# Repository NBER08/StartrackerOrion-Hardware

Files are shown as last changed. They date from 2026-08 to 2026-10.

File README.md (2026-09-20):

<p align="center" width="100%">
  
</p>

<h1 align="center">Orion Main</h1>

<p align="center" width="100%">
  <a href="https://github.com/NBER08/StartrackerOrion-Hardware/actions/workflows/ci.yaml">
    
  </a>
</p>

<p align="center" width="100%">
    
</p>

***

<p align="center">
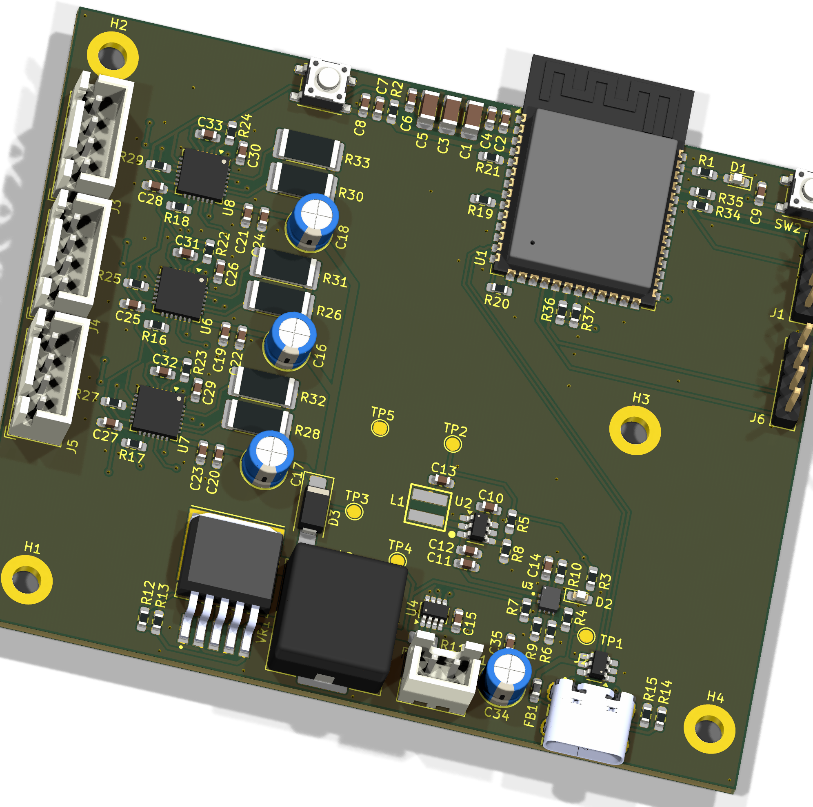
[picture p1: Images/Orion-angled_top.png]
3D Top Angled
  
&nbsp; &nbsp; &nbsp; &nbsp;
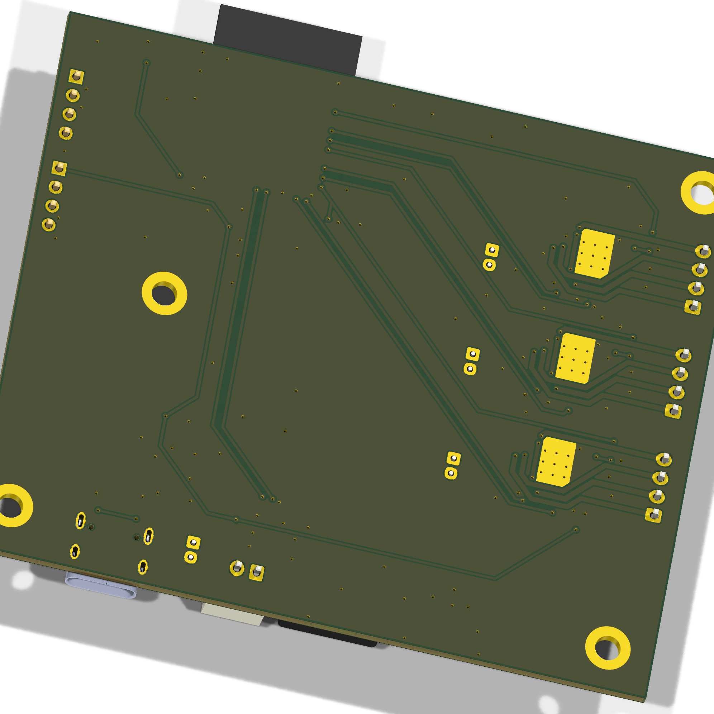
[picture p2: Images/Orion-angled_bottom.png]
3D Bottom Angled
  
</p>

***

## SPECIFICATIONS

| Parameter | Value | 
| --- | --- |
| Dimensions | 86.06 × 71.93 mm |

***

## DIRECTORY STRUCTURE

    .
    ├─ Computations       # Misc calculations
    ├─ HTML               # HTML files for generated webpage
    ├─ Images             # Pictures and renders
    │
    ├─ kibot_resources    # External resources for KiBot
    │  ├─ colors          # Color theme for KiCad
    │  ├─ fonts           # Fonts used in the project
    │  ├─ scripts         # External scripts used with KiBot
    │  └─ templates       # Templates for KiBot generated reports
    │
    ├─ kibot_yaml         # KiBot YAML config files
    ├─ KiRI               # KiRI (PCB diff viewer) files
    │
    ├─ lib                # KiCad footprint and symbol libraries
    │  ├─ 3d_models       # Component 3D models
    │  ├─ lib_fp          # Footprint libraries
    │  └─ lib_sym         # Symbol libraries
    │
    ├─ Logos              # Logos
    │
    ├─ Manufacturing      # Assembly and fabrication documents
    │  ├─ Assembly        # Assembly documents (BoM, pos, notes)
    │  │
    │  └─ Fabrication     # Fabrication documents (ZIP, notes)
    │     ├─ Drill Tables # CSV drill tables
    │     └─ Gerbers      # Gerbers
    │
    ├─ Report             # Reports for ERC/DRC
    ├─ Schematic          # PDF of schematic
    ├─ Templates          # Title block templates
    ├─ Testing
    │  └─ Testpoints      # Testpoints tables      
    │
    └─ Variants           # Outputs for assembly variants

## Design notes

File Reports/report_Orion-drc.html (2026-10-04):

Logo

(https://github.com/INTI-CMNB/KiBot/) | DRC report for Orion
| PCB: Orion Revision: + (Unreleased) Date: 2026-10-04T15:30:59 KiCad Version: 10.0.5 | Errors: 0 (+7 excluded) Warnings: 0 (+4 excluded) Total: 0 (+11 excluded)

✔

Violations

Type | Description | Details
silk_edge_clearance | Silkscreen clipped by board edge | @(64.2638 mm, 33.9054 mm): Rectangle on Edge.Cuts @(128.577 mm, 105.0246 mm): Segment of J2 on F.Silkscreen
silk_edge_clearance | Silkscreen clipped by board edge | @(64.2638 mm, 33.9054 mm): Rectangle on Edge.Cuts @(137.517 mm, 106.3046 mm): Segment of J2 on F.Silkscreen
silk_edge_clearance | Silkscreen clipped by board edge | @(64.2638 mm, 33.9054 mm): Rectangle on Edge.Cuts @(113.6238 mm, 27.7132 mm): Segment of U1 on F.Silkscreen
silk_edge_clearance | Silkscreen clipped by board edge | @(64.2638 mm, 33.9054 mm): Rectangle on Edge.Cuts @(132.0238 mm, 27.7132 mm): Segment of U1 on F.Silkscreen
clearance | Clearance violation (rule 'pad to pad clearance (without hole, different nets)' clearance 0.2000 mm; actual 0.1500 mm) | @(114.0667 mm, 94.7782 mm): Pad 2 [Net-(BT1-+)] of U4 on L1 (Sig, PWR) @(114.7167 mm, 94.7782 mm): Pad 3 [GND] of U4 on L1 (Sig, PWR)
clearance | Clearance violation (rule 'pad to pad clearance (without hole, different nets)' clearance 0.2000 mm; actual 0.1500 mm) | @(114.0667 mm, 94.7782 mm): Pad 2 [Net-(BT1-+)] of U4 on L1 (Sig, PWR) @(113.4167 mm, 94.7782 mm): Pad 1 [+BATT] of U4 on L1 (Sig, PWR)
clearance | Clearance violation (rule 'pad to pad clearance (without hole, different nets)' clearance 0.2000 mm; actual 0.1500 mm) | @(114.7167 mm, 94.7782 mm): Pad 3 [GND] of U4 on L1 (Sig, PWR) @(115.3667 mm, 94.7782 mm): Pad 4 [+3.3V] of U4 on L1 (Sig, PWR)
clearance | Clearance violation (rule 'pad to pad clearance (without hole, different nets)' clearance 0.2000 mm; actual 0.1500 mm) | @(115.3667 mm, 92.5032 mm): Pad 5 [/Project Architecture/MCU/INA_SCL] of U4 on L1 (Sig, PWR) @(114.7167 mm, 92.5032 mm): Pad 6 [/Project Architecture/MCU/INA_SDA] of U4 on L1 (Sig, PWR)
clearance | Clearance violation (rule 'pad to pad clearance (without hole, different nets)' clearance 0.2000 mm; actual 0.1500 mm) | @(114.7167 mm, 92.5032 mm): Pad 6 [/Project Architecture/MCU/INA_SDA] of U4 on L1 (Sig, PWR) @(114.0667 mm, 92.5032 mm): Pad 7 [GND] of U4 on L1 (Sig, PWR)
hole_clearance | Hole clearance violation (rule 'NPTH with copper around' clearance 0.2000 mm; actual 0.1751 mm) | @(129.847 mm, 98.9496 mm): Pad A1_B12 [GND] of J2 on L1 (Sig, PWR) @(130.157 mm, 100.0246 mm): NPTH pad of J2
hole_clearance | Hole clearance violation (rule 'NPTH with copper around' clearance 0.2000 mm; actual 0.1751 mm) | @(136.247 mm, 98.9496 mm): Pad B1_A12 [GND] of J2 on L1 (Sig, PWR) @(135.937 mm, 100.0246 mm): NPTH pad of J2

Generated by KiBot (https://github.com/INTI-CMNB/KiBot/) v1.9.2

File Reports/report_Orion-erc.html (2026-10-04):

Logo

(https://github.com/INTI-CMNB/KiBot/) | ERC report for Orion
| Schematic: Orion Revision: + (Unreleased) Date: 2026-10-04T15:30:54 KiCad Version: 10.0.5 | Errors: 0 (+1 excluded) Warnings: 1 (+15 excluded) Total: 1 (+16 excluded)

Sheet / (Orion.kicad_sch)

Type | Description | Details
footprint_link_issues | The current configuration does not include the footprint library 'TPS2121RUXR' | @(0.8255 mm, 0.8636 mm): Symbol U3 [TPS2121RUXR]
lib_symbol_mismatch | Symbol doesn't match copy in library | @(0.6985 mm, 0.5588 mm): Symbol C30 [C_Small]
lib_symbol_mismatch | Symbol doesn't match copy in library | @(0.8382 mm, 0.8001 mm): Symbol C33 [C_Small]
lib_symbol_mismatch | Symbol doesn't match copy in library | @(1.5367 mm, 0.5334 mm): Symbol C26 [C_Small]
lib_symbol_mismatch | Symbol doesn't match copy in library | @(1.6764 mm, 0.7747 mm): Symbol C31 [C_Small]
lib_symbol_mismatch | Symbol doesn't match copy in library | @(2.3749 mm, 0.5461 mm): Symbol C29 [C_Small]
lib_symbol_mismatch | Symbol doesn't match copy in library | @(2.5146 mm, 0.7874 mm): Symbol C32 [C_Small]
lib_symbol_mismatch | Symbol doesn't match copy in library | @(0.6223 mm, 1.016 mm): Symbol C14 [C_Small]
lib_symbol_mismatch | Symbol doesn't match copy in library | @(2.0574 mm, 0.7112 mm): Symbol C10 [C_Small]

Sheet /Project Architecture/Power/ (power.kicad_sch)

Type | Description | Details
power_pin_not_driven | Input Power pin not driven by any Output Power pins | @(1.7907 mm, 0.7112 mm): Symbol U2 Pin 3 [VIN, Power input, Line]

Sheet /Project Architecture/Connectors/ (conn.kicad_sch)

Type | Description | Details
multiple_net_names | More than one name given to this bus or net | @(0.7747 mm, 0.5969 mm): Symbol #PWR030 Pin 1 [Power input, Line] @(0.6731 mm, 0.7493 mm): Symbol J2 Hidden pin SH2 [SHELL_GND, Power input, Line]

Sheet /Project Architecture/Drivers/ (drivers.kicad_sch)

Type | Description | Details
multiple_net_names | More than one name given to this bus or net | @(0.3429 mm, 0.8001 mm): Global Label 'RX1' @(0.5461 mm, 1.2827 mm): Global Label 'TX1'
multiple_net_names | More than one name given to this bus or net | @(0.5461 mm, 1.3081 mm): Global Label 'RX1' @(0.5461 mm, 1.2827 mm): Global Label 'TX1'
multiple_net_names | More than one name given to this bus or net | @(1.3843 mm, 1.2827 mm): Global Label 'RX2' @(1.1303 mm, 0.7239 mm): Global Label 'TX2'
multiple_net_names | More than one name given to this bus or net | @(1.3843 mm, 1.2827 mm): Global Label 'RX2' @(1.3843 mm, 1.2573 mm): Global Label 'TX2'
multiple_net_names | More than one name given to this bus or net | @(1.9812 mm, 0.7874 mm): Global Label 'RX3' @(1.9812 mm, 0.7366 mm): Global Label 'TX3'
multiple_net_names | More than one name given to this bus or net | @(2.2352 mm, 1.2954 mm): Global Label 'RX3' @(2.2352 mm, 1.27 mm): Global Label 'TX3'

Generated by KiBot (https://github.com/INTI-CMNB/KiBot/) v1.9.2

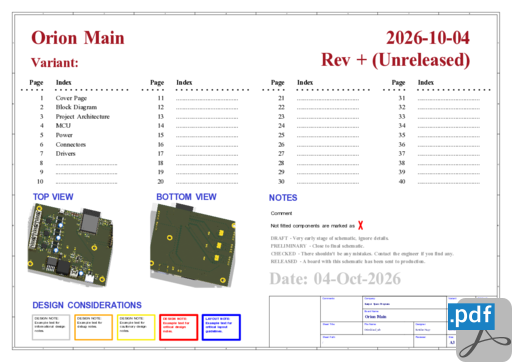
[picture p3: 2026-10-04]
HTML/images/cat_pdf_schematic_Orion-schematic.png

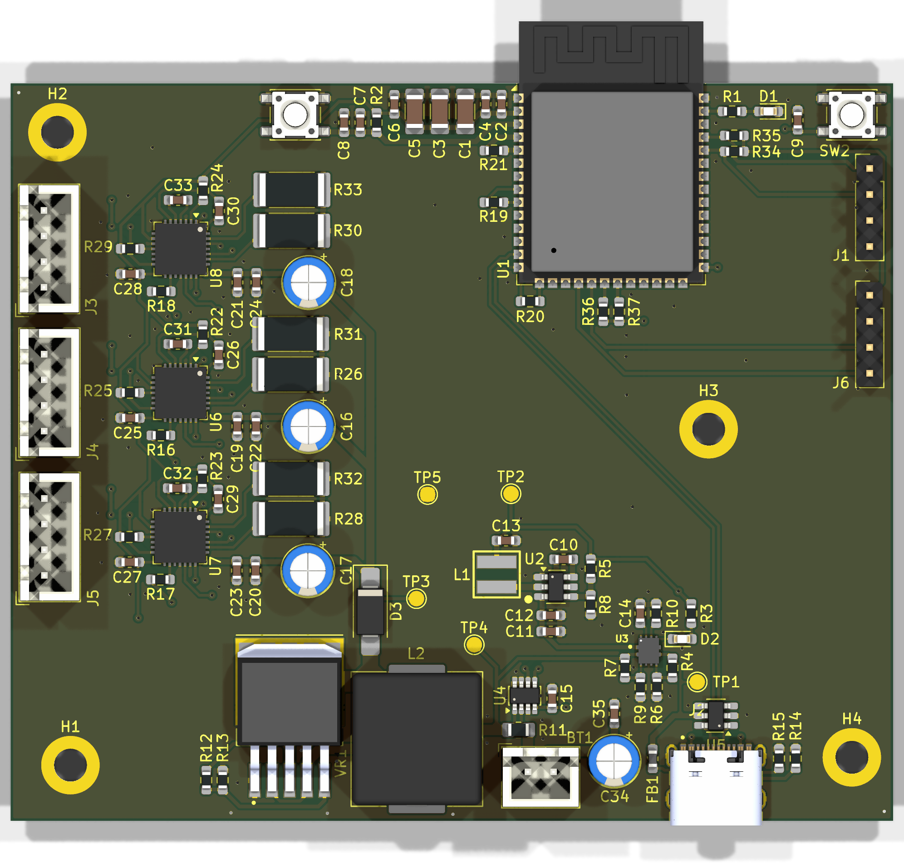
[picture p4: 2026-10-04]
Images/Orion-top.png

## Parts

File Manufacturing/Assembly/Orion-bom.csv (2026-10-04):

Row | Quantity Per PCB | References | Value | Datasheet | Footprint | Description | Manufacturer | Manufacturer Part Number | Supplier Part Number
1 | 1 | BT1 | Battery |  | JST_XH_B2B-XH-A_1x02_P2.50mm_Vertical | Multiple-cell battery
2 | 1 | C2 | 22p |  | C_0603_1608Metric_Pad1.08x0.95mm_HandSolder | Unpolarized capacitor
3 | 3 | C31 C32 C33 | 22n |  | C_0603_1608Metric_Pad1.08x0.95mm_HandSolder | 50V
4 | 19 | C6 C8 C9 C10 C12 C15 C19 C20 C21 C22 C23 C24 C25 C26 C27 C28 C29 C30 C35 | 100n |  | C_0603_1608Metric_Pad1.08x0.95mm_HandSolder | Unpolarized capacitor Unpolarized capacitor, small symbol 16V
5 | 2 | C11 C14 | 1u |  | C_0603_1608Metric_Pad1.08x0.95mm_HandSolder | Unpolarized capacitor Unpolarized capacitor, small symbol
6 | 1 | C7 | 10u |  | C_0603_1608Metric_Pad1.08x0.95mm_HandSolder | Unpolarized capacitor
7 | 1 | C4 | 22u |  | C_0603_1608Metric_Pad1.08x0.95mm_HandSolder | Unpolarized capacitor
8 | 2 | C13 L2 | 47u |  | C_0603_1608Metric_Pad1.08x0.95mm_HandSolder | Unpolarized capacitor Inductor
9 | 7 | C1 C3 C5 C16 C17 C18 C34 | 100u |  | C_1206_3216Metric_Pad1.33x1.80mm_HandSolder | Unpolarized capacitor low ESR
10 | 2 | D1 D2 | RED |  | LED_0603_1608Metric_Pad1.05x0.95mm_HandSolder | Light emitting diode
11 | 1 | D3 | SS34 | https://www.vishay.com/docs/88751/ss32.pdf | D_SMA_Handsoldering | 40V 3A Schottky Diode, SMA
12 | 1 | FB1 | LI0603G121R-10 |  | L_0603_1608Metric_Pad1.05x0.95mm_HandSolder | Ferrite bead
13 | 5 | J1 J3 J4 J5 J6 | Conn_01x04_Pin |  | PinHeader_1x04_P2.54mm_Vertical | Generic connector, single row, 01x04, script generated
14 | 1 | J2 | USB4105GFA |  | GCT_USB4105GFA | USB-C (USB TYPE-C) USB 2.0 Receptacle Connector 24 (16+8 Dummy) Position Surface Mount, Right Angle; Through Hole | Global Connector Technology
15 | 1 | L1 | 5u6 |  | WE-XHMI_4040 | Inductor
16 | 1 | R11 | 10m |  | R_0805_2012Metric_Pad1.20x1.40mm_HandSolder | Resistor
17 | 6 | R26 R28 R30 R31 R32 R33 | 220m |  | R_2512_6332Metric_Pad1.40x3.35mm_HandSolder | Resistor, small symbol
18 | 2 | R1 R3 | 120 |  | R_0603_1608Metric_Pad0.98x0.95mm_HandSolder | Resistor
19 | 1 | R13 | 330 |  | R_0603_1608Metric_Pad0.98x0.95mm_HandSolder | Resistor
20 | 6 | R16 R17 R18 R19 R20 R21 | 1k |  | R_0603_1608Metric_Pad0.98x0.95mm_HandSolder | Resistor, small symbol
21 | 1 | R12 | 2k8 |  | R_0603_1608Metric_Pad0.98x0.95mm_HandSolder | Resistor
22 | 2 | R14 R15 | 5k1 |  | R_0603_1608Metric_Pad0.98x0.95mm_HandSolder | Resistor
23 | 7 | R2 R22 R23 R24 R25 R27 R29 | 10k |  | R_0603_1608Metric_Pad0.98x0.95mm_HandSolder | Resistor Resistor, small symbol
24 | 1 | R10 | 21k5 |  | R_0603_1608Metric_Pad0.98x0.95mm_HandSolder | Resistor, small symbol
25 | 1 | R8 | 22k1 |  | R_0603_1608Metric_Pad0.98x0.95mm_HandSolder | Resistor, small symbol
26 | 2 | R6 R9 | 33k |  | R_0603_1608Metric_Pad0.98x0.95mm_HandSolder | Resistor, small symbol
27 | 5 | R4 R34 R35 R36 R37 | 47k |  | R_0603_1608Metric_Pad0.98x0.95mm_HandSolder | Resistor, small symbol
28 | 1 | R7 | 82k |  | R_0603_1608Metric_Pad0.98x0.95mm_HandSolder | Resistor, small symbol
29 | 1 | R5 | 100k |  | R_0603_1608Metric_Pad0.98x0.95mm_HandSolder | Resistor, small symbol
30 | 1 | SW2 | BOOT |  | SW_SPST_PTS647_Sx38 | Push button switch, generic, two pins
31 | 1 | SW1 | RST |  | SW_SPST_PTS647_Sx38 | Push button switch, generic, two pins
32 | 1 | U1 | ESP32-S3-WROOM-1 | https://www.espressif.com/sites/default/files/documentation/esp32-s3-wroom-1_wroom-1u_datasheet_en.pdf | ESP32-S3-WROOM-1_novias | RF Module, ESP32-S3 SoC, Wi-Fi 802.11b/g/n, Bluetooth, BLE, 32-bit, 3.3V, onboard antenna, SMD
33 | 1 | U4 | INA219BxDCN | http://www.ti.com/lit/ds/symlink/ina219.pdf | SOT-23-8 | Zero-Drift, HighAccuracy, Bidirectional Current/Power Monitor (0-26V) With I2C Interface, SOT-23-8
34 | 1 | U2 | LMR51420 | https://www.ti.com/lit/ds/symlink/lmr51430.pdf | SOT-23-6_Handsoldering | 4.5-V to 36-V, 3-A synchronous buck converter with 40-µA IQ, SOT-23-6
35 | 1 | U5 | SRV05-4 | http://www.onsemi.com/pub/Collateral/SRV05-4-D.PDF | SOT-23-6_Handsoldering | ESD Protection Diodes with Low Clamping Voltage, SOT-23-6
36 | 3 | U6 U7 U8 | TMC2209-LA | https://www.analog.com/media/en/technical-documentation/data-sheets/TMC2209_datasheet_rev1.09.pdf | VQFN-28-1EP_5x5mm_P0.5mm_EP3.7x3.7mm | 2-phase stepper motor driver, 256 µSteps, 2.8A peak, 2.0A RMS, VS = 4.75..29V, STEP/DIR and UART interface, VQFN-28
37 | 1 | U3 | TPS2121RUXR |  | IC_TPS2121RUXR | 2.7-V to 22-V, 56-mΩ, 4.5-A, power mux with seamless switchover | TEXAS INSTRUMENTS
38 | 1 | VR1 | XL6009 |  | DPAK170P1435X465-6N | The XL6009 regulator is a wide input range, current mode, DC/DC converter which is capable of generating either positive or negative output voltages. | XLSEMI

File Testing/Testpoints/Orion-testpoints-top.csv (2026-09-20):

Ref. | Net | X [mm] | Y [mm]
TP1 | VBUS | 67.22 | 13.70
TP2 | +3.3V | 49.06 | 32.06
TP3 | VM | 39.84 | 21.83
TP4 | +BATT | 45.48 | 17.33
TP5 | GND | 40.93 | 31.99

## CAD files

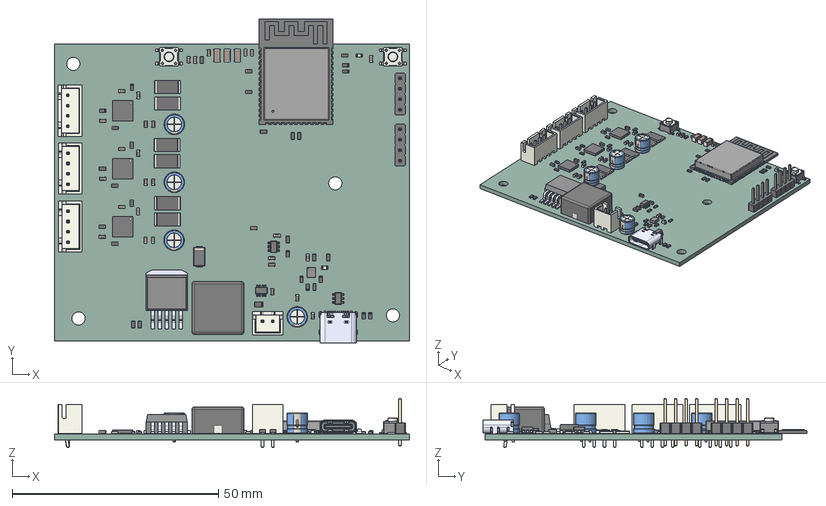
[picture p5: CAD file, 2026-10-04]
3D/Orion.step
86.1 x 78.4 x 11.9 mm
C_0603_1608Metric x 28
R_2512_6332Metric x 6
SOT-23-6 x 2
LED_0603_1608Metric x 2
SW_SPST_PTS647Sx38 x 2
JST_B4B_XH_A x 3
R_0603_1608Metric x 30
USB4105GFA_USB4105GFA
CP_Radial_D50mm_P200mm x 4
PinHeader_1x04_P254mm_Vertical x 2
SOT-23-8
JST_B2B_XH_A
XL6009
QFN-28-1EP_5x5mm_Pitch0.5mm x 3
L_Changjiang_FXL1365
C_1206_3216Metric x 3
L_0603_1608Metric
TPS2121RUXR
R_0805_2012Metric
D_SMA
ESP32-S3-WROOM-1
kibot_7lxlktsg_PCB

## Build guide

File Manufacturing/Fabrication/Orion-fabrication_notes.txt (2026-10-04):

FABRICATION NOTES (UNLESS OTHERWISE SPECIFIED)

1)	FABRICATE PER IPC-6012A CLASS 2.

2)	OUTLINE DEFINED IN SEPARATE GERBER FILE WITH
	"Edge_Cuts.GBR" SUFFIX.

	DIMENSIONS OF CIRCUMSIZED RECTANGLE SHOWN ON THIS
	DRAWING FOR REFERENCE ONLY.

3)	SEE SEPARATE DRILL FILES WITH ".DRL" SUFFIX 
	FOR HOLE LOCATIONS.

	SELECTED HOLE LOCATIONS SHOWN ON THIS DRAWING 
	FOR REFERENCE ONLY.

4)	SURFACE FINISH: ENIG

5)	SOLDERMASK ON BOTH SIDES OF THE BOARD SHALL 
	BE LPI, COLOR GREEN.

6)	SILK SCREEN LEGEND TO BE APPLIED PER LAYER 
	STACKUP USING YELLOW NON-CONDUCTIVE EPOXY INK.

7)	ALL VIAS ARE TENTED ON BOTH SIDES UNLESS 
	SOLDERMASK OPENED IN GERBER.

8)	VENDOR SHOULD FOLLOW ROHS COMPLIANT PROCESS 
	AND Pb FREE FOR MANUFACTURING

9)	PCB MATERIAL REQUIREMENTS:

	A.	FLAMMABILITY RATING MUST MEET OR EXCEED 
		UL94V-0 REQUIREMENTS.
	B.	Tg 170 C OR EQUIVALENT.
	C.	EQUIVALENT MATERIAL SHALL BE RoHS COMPLIANT, 
		HALOGEN FREE AND APPROVED BY KARPAT SPACE PROGRAM.

10)	DESIGN GEOMETRY MINIMUM FEATURE SIZES:

	BOARD SIZE				86.055 × 71.933 mm
	BOARD THICKNESS		1.660 mm
	TRACE WIDTH			0.200 mm
	TRACE TO TRACE		0.200 mm
	MIN. HOLE (PTH)			0.300 mm
	MIN. HOLE (NPTH)		0.650 mm
	ANNULAR RING			0.200 mm
	COPPER TO HOLE		0.250 mm
	COPPER TO EDGE		0.250 mm
	HOLE TO HOLE			0.100 mm

11)	REFER TO IMPEDANCE TABLE FOR IMPEDANCE CONTROL REQUIREMENTS.

12)	CONFIRM SPACE WIDTHS AND SPACINGS.

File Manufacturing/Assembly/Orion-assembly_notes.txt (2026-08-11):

ASSEMBLY NOTES (UNLESS OTHERWISE SPECIFIED)

1)	DO NOT POPULATE PARTS ARE MARKED WITH A RED CROSS.

2)	DO NOT POPULATE PARTS ARE NOT PRESENT IN THE BOM.

3)	IF CONFLICTING INFORMATION IS FOUND BETWEEN THE ASSEMBLY
	FILE AND BOM, BOM SHOULD BE USED AS THE MAIN SOURCE.

4)	CONFORMAL COATING IS NOT REQUIRED.

5)	DOT IDENTIFIES PIN #1 LOCATION AND DEVICE ORIENTATION
	WHEN VIEWED FROM THE TOP.

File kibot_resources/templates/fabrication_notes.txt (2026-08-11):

FABRICATION NOTES (UNLESS OTHERWISE SPECIFIED)

1)	FABRICATE PER IPC-6012A CLASS 2.

2)	OUTLINE DEFINED IN SEPARATE GERBER FILE WITH
	"Edge_Cuts.GBR" SUFFIX.

	DIMENSIONS OF CIRCUMSIZED RECTANGLE SHOWN ON THIS
	DRAWING FOR REFERENCE ONLY.

3)	SEE SEPARATE DRILL FILES WITH ".DRL" SUFFIX 
	FOR HOLE LOCATIONS.

	SELECTED HOLE LOCATIONS SHOWN ON THIS DRAWING 
	FOR REFERENCE ONLY.

4)	SURFACE FINISH: ${pcb_finish_cap}

5)	SOLDERMASK ON BOTH SIDES OF THE BOARD SHALL 
	BE LPI, COLOR ${solder_mask_color_text_cap}.

6)	SILK SCREEN LEGEND TO BE APPLIED PER LAYER 
	STACKUP USING ${silk_screen_color_text_cap} NON-CONDUCTIVE EPOXY INK.

7)	ALL VIAS ARE TENTED ON BOTH SIDES UNLESS 
	SOLDERMASK OPENED IN GERBER.

8)	VENDOR SHOULD FOLLOW ROHS COMPLIANT PROCESS 
	AND Pb FREE FOR MANUFACTURING

9)	PCB MATERIAL REQUIREMENTS:

	A.	FLAMMABILITY RATING MUST MEET OR EXCEED 
		UL94V-0 REQUIREMENTS.
	B.	Tg 170 C OR EQUIVALENT.
	C.	EQUIVALENT MATERIAL SHALL BE RoHS COMPLIANT, 
		HALOGEN FREE AND APPROVED BY ${COMPANY_cap}.

10)	DESIGN GEOMETRY MINIMUM FEATURE SIZES:

	BOARD SIZE				${bb_w_mm} × ${bb_h_mm} mm
	BOARD THICKNESS		${thickness_mm} mm
	TRACE WIDTH			${track_mm} mm
	TRACE TO TRACE		${clearance_mm} mm
	MIN. HOLE (PTH)			${drill_pth_real_mm} mm
	MIN. HOLE (NPTH)		${drill_npth_real_mm} mm
	ANNULAR RING			${oar_mm} mm
	COPPER TO HOLE		${c2h_mm} mm
	COPPER TO EDGE		${c2e_mm} mm
	HOLE TO HOLE			${h2h_mm} mm
#?stackup and impedance_controlled

#?stackup and impedance_controlled
11)	REFER TO IMPEDANCE TABLE FOR IMPEDANCE CONTROL REQUIREMENTS.
#?stackup and impedance_controlled

#?stackup and impedance_controlled
12)	CONFIRM SPACE WIDTHS AND SPACINGS.

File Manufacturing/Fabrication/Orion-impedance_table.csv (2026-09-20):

Transmission Line | Impedance [ohms] | Tolerance [ohms] | Layer | Trace Width [mm] | Gap [mm] | Ref. Layers
Edge-Coupled Coated Microstrip | 100 | ±10 % | L1 | 0.285 | 0.1 | L2

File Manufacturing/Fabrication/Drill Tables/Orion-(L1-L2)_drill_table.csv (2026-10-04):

Count | Hole Size | Plated | Hole Shape | Drill Layer Pair | Hole Type
187 | 0.30mm (11.81mils) | PTH | Round | L1 (Sig, PWR) - L4 (Sig, PWR) | Via
4 | 0.60mm (23.62mils) | PTH | Slot | L1 (Sig, PWR) - L4 (Sig, PWR) | Pad
8 | 0.80mm (31.50mils) | PTH | Round | L1 (Sig, PWR) - L4 (Sig, PWR) | Pad
12 | 0.95mm (37.40mils) | PTH | Round | L1 (Sig, PWR) - L4 (Sig, PWR) | Pad
10 | 1.00mm (39.37mils) | PTH | Round | L1 (Sig, PWR) - L4 (Sig, PWR) | Pad
4 | 3.20mm (125.98mils) | PTH | Round | L1 (Sig, PWR) - L4 (Sig, PWR) | Pad
Total 225

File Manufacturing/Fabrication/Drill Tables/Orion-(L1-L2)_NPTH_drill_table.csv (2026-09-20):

Count | Hole Size | Plated | Hole Shape | Drill Layer Pair | Hole Type
2 | 0.65mm (25.59mils) | NPTH | Round | L1 (Sig, PWR) - L4 (Sig, PWR) | Mechanical
Total 2

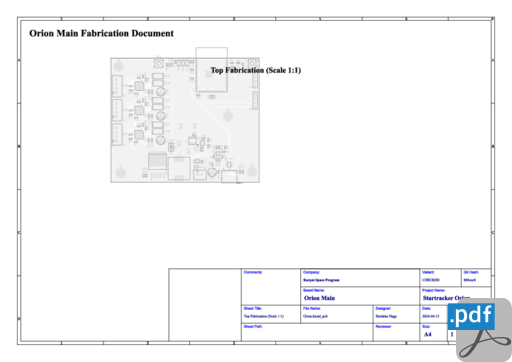
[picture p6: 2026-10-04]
HTML/images/cat_pdf_fabrication_Orion-fabrication.png

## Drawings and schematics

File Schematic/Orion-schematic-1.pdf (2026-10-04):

# Orion Main

# Variant:

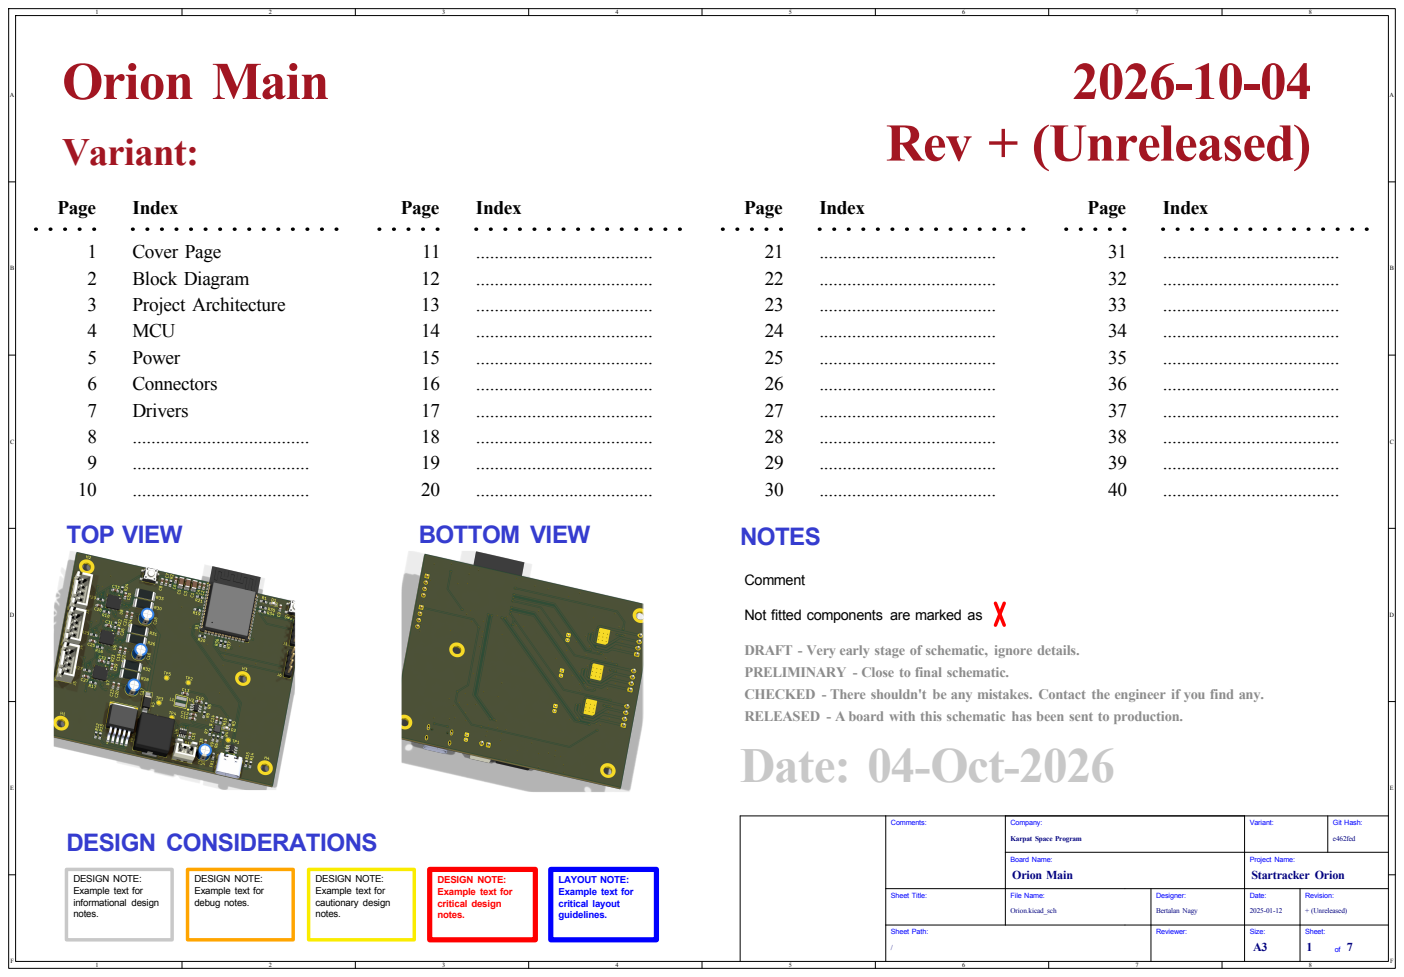
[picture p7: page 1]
Sheet: of 7; Size: A3; Orion.kicad_sch; Bertalan Nagy Board Name: Company:; Variant: Karpat Space Program; Orion Main; Startracker Orion; Sheet Title:; File Name:; /Sheet Path: Comments:; Git Hash: e462fed Block Diagram; kibot_image_png_3d_viewer_angled_top; DESIGN NOTE:; kibot_image_png_3d_viewer_angled_bottom; LAYOUT NOTE:; Page; ...................................... MCU; Project Architecture; Cover Page Block Diagram; Index; TOP VIEW; BOTTOM VIEW; DESIGN CONSIDERATIONS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

...................................... DRAFT - Very early stage of schematic, ignore details.

Not fitted components are marked as

PRELIMINARY - Close to final schematic.
CHECKED - There shouldn't be any mistakes. Contact the engineer if you find any.
RELEASED - A board with this schematic has been sent to production.
Date: 04-Oct-2026

Revision: + (Unreleased) Date: Project Name: 2025-01-12 Reviewer: Designer:

DESIGN NOTE:
Example text for
informational design
notes.

debug notes.

critical design

cautionary design

critical layout
guidelines.

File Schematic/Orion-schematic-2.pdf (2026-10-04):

## Page 4

# [2] Block Diagram

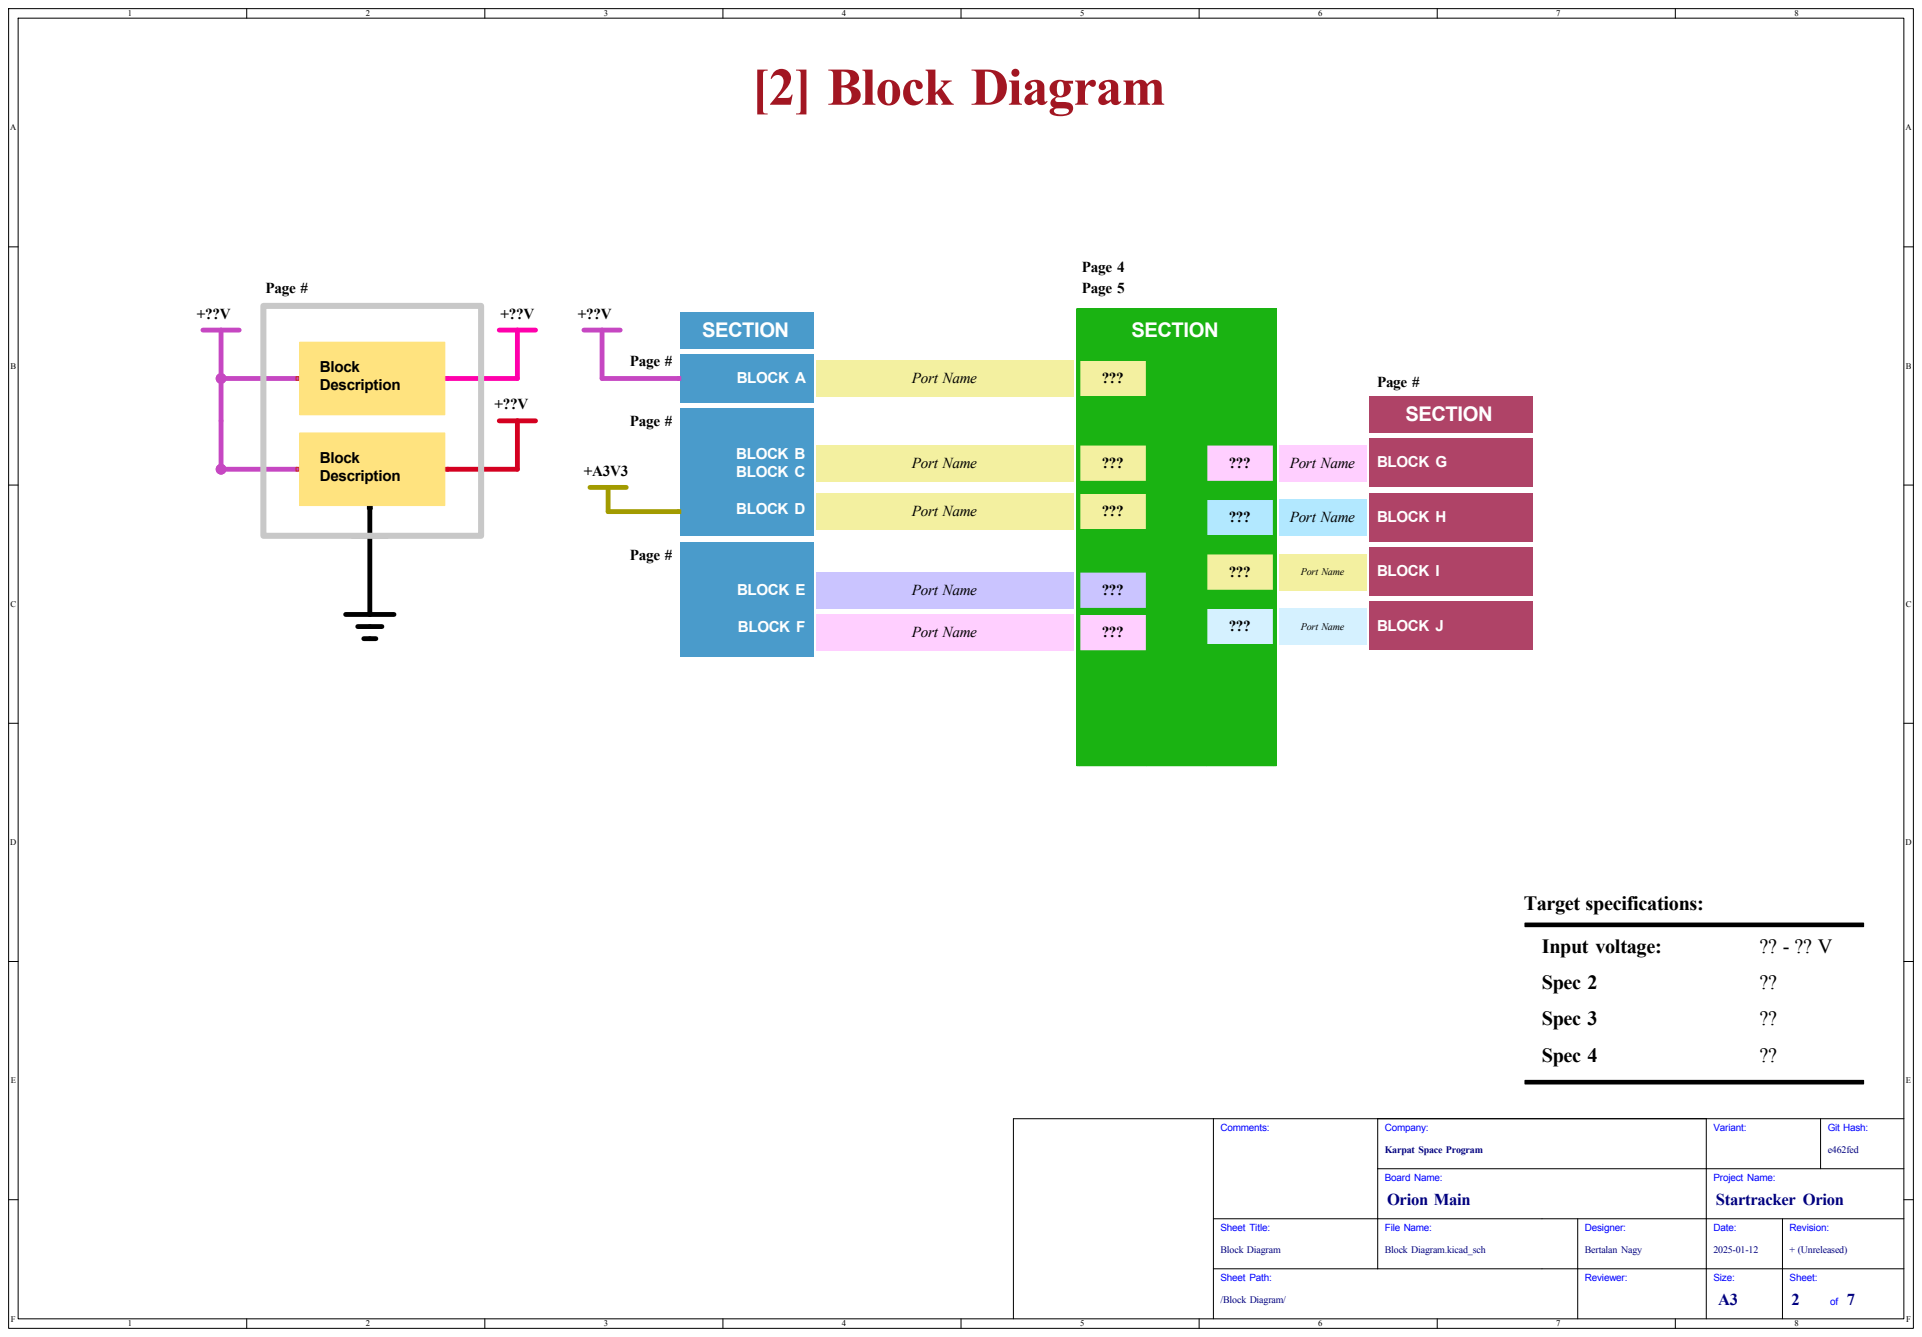
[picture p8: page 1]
Sheet: of 7; Size: A3; Revision: + (Unreleased) Date: Project Name: 2025-01-12 Reviewer: Designer: Block Diagram.kicad_sch; Bertalan Nagy Board Name: Company:; Variant: Karpat Space Program; Orion Main; Startracker Orion; Sheet Title:; File Name:; Comments:; Git Hash: e462fed; Page #; Input voltage:; BLOCK J; BLOCK I; BLOCK H; SECTION; BLOCK G; Spec 3; Spec 4; Spec 2; Port Name; Page 5; Port Name ???; Target specifications:; Block Description; BLOCK B BLOCK C; BLOCK D; BLOCK E; BLOCK F; BLOCK A

Port Name

/Block Diagram/ Sheet Path: Block Diagram

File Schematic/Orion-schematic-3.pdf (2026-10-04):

# INA_SDA MCU [3] Project Architecture

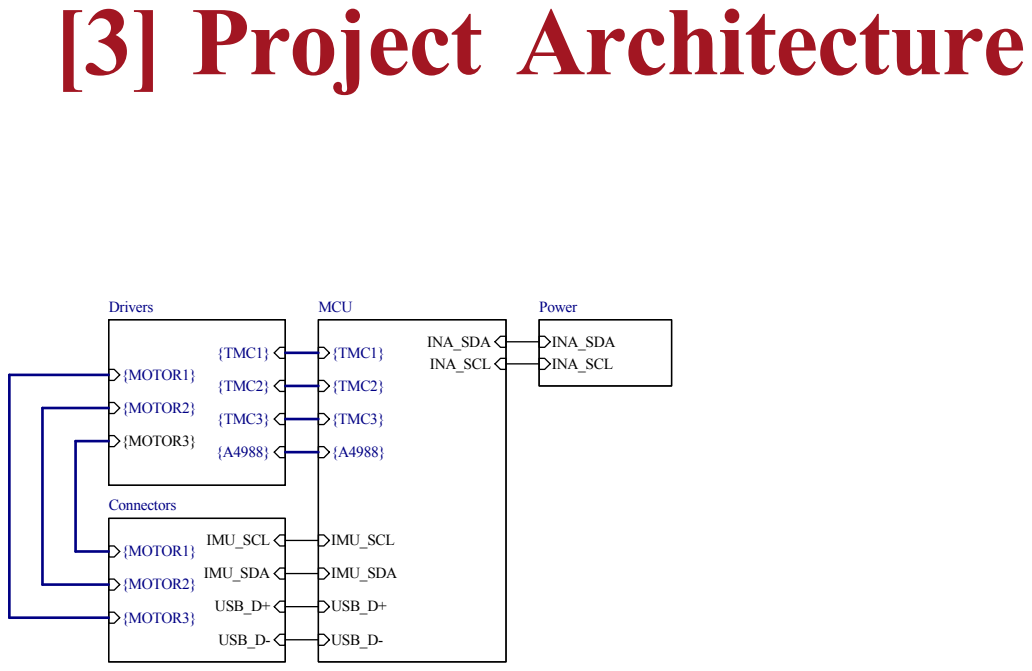
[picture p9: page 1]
Sheet: of 7; Size: A3; Project Architecture.kicad_sch; Bertalan Nagy Board Name: Company:; Variant: Karpat Space Program; Orion Main; Startracker Orion; Sheet Title:; File Name:; /Project Architecture/ Sheet Path: Project Architecture Comments:; Git Hash: e462fed; IMU_SCL; IMU_SDA; USB_D+; USB_D-; {MOTOR1}; {MOTOR2}; {MOTOR3} Connectors; {TMC1}; {MOTOR3}; {TMC2}; {TMC3} Drivers; INA_SCL; INA_SDA; Power; {TMC3}

Revision: + (Unreleased) Date: Project Name: 2025-01-12 Reviewer: Designer:

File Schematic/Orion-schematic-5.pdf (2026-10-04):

# R10 21k5 R3

# [5] Power

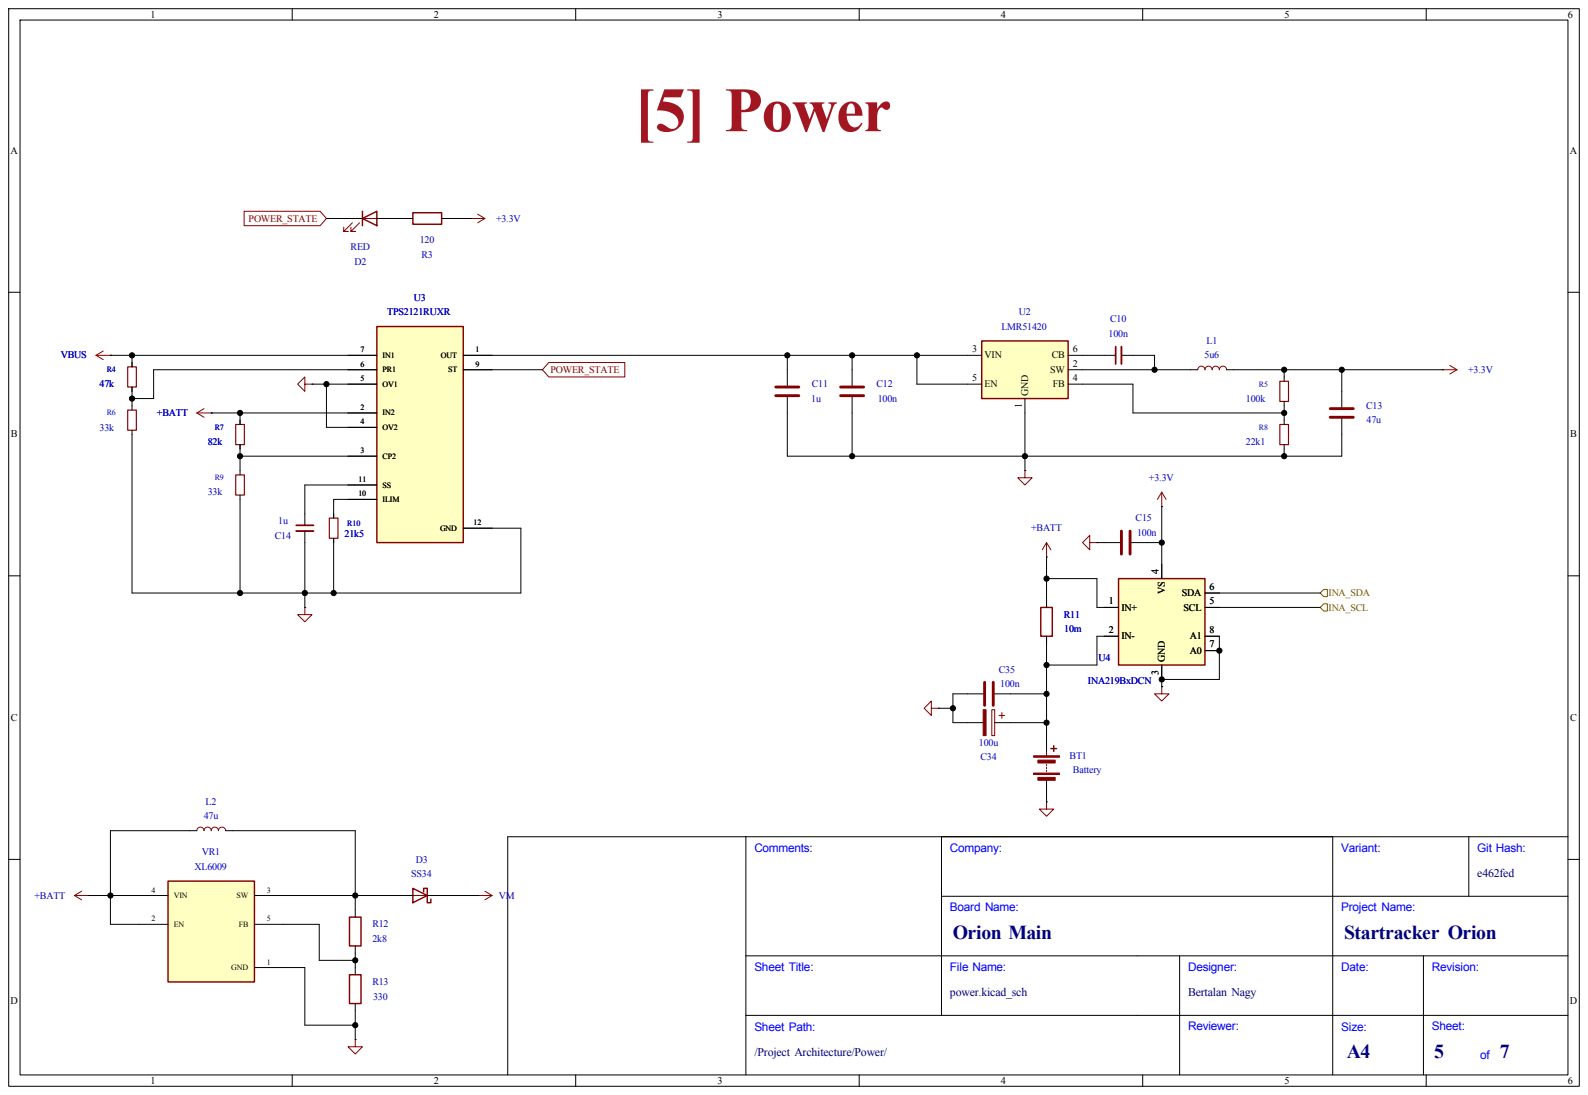
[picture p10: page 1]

1 SW 2 VIN 3 FB 4 EN 5 CB 6 U2 LMR51420 C12

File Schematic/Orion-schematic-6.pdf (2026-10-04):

# [6] Connectors

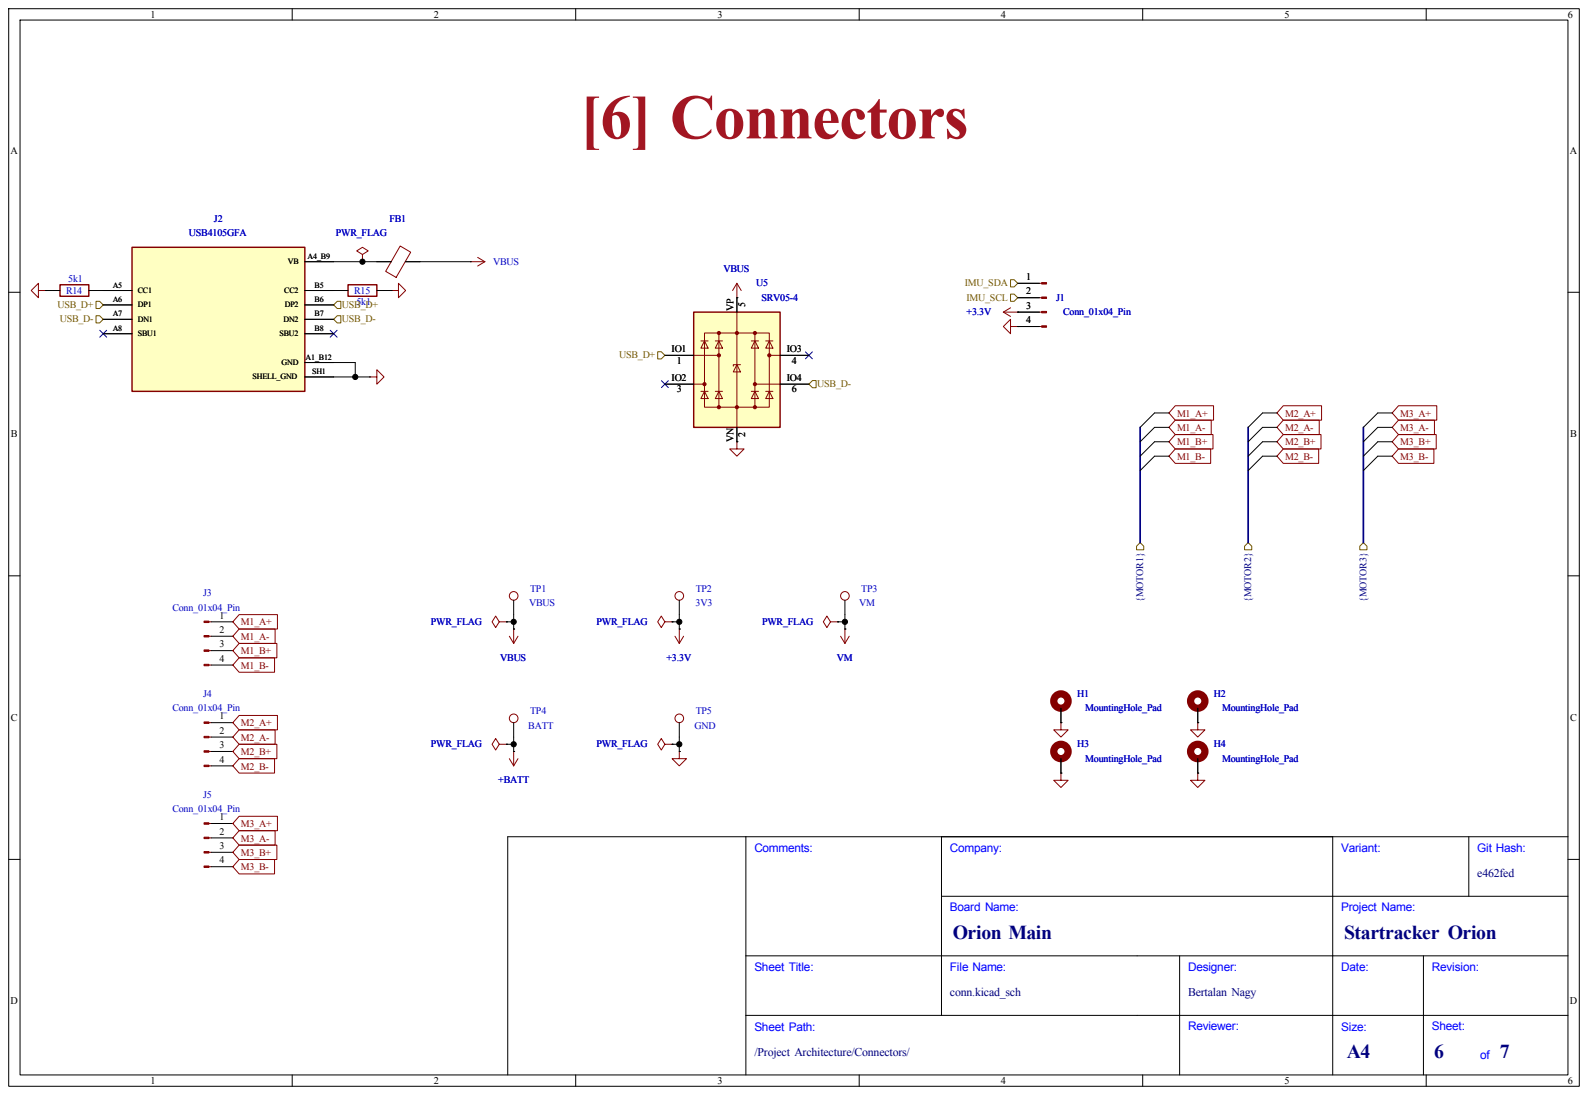
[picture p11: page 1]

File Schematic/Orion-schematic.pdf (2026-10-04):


...................................... DRAFT - Very early stage of schematic, ignore details.

Not fitted components are marked as

PRELIMINARY - Close to final schematic.
CHECKED - There shouldn't be any mistakes. Contact the engineer if you find any.
RELEASED - A board with this schematic has been sent to production.
Date: 04-Oct-2026

Revision: + (Unreleased) Date: Project Name: 2025-01-12 Reviewer: Designer:


Port Name

/Block Diagram/ Sheet Path: Block Diagram


Revision: + (Unreleased) Date: Project Name: 2025-01-12 Reviewer: Designer:

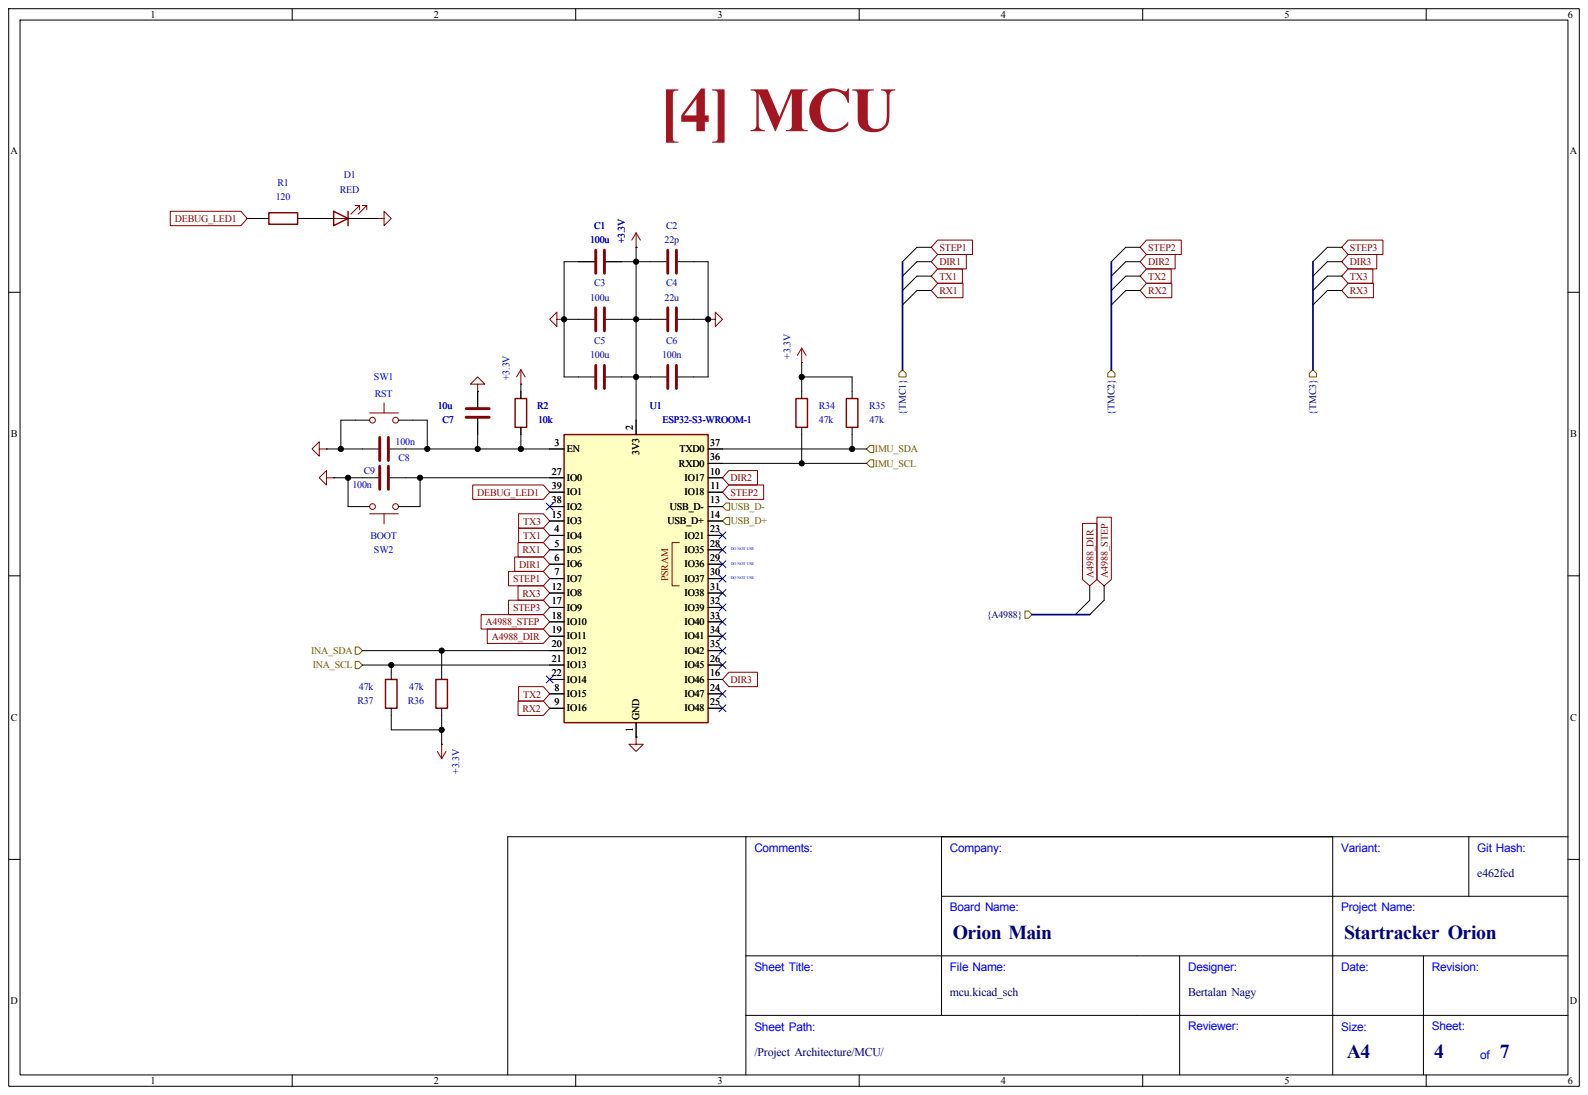
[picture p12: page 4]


1 SW 2 VIN 3 FB 4 EN 5 CB 6 U2 LMR51420 C12


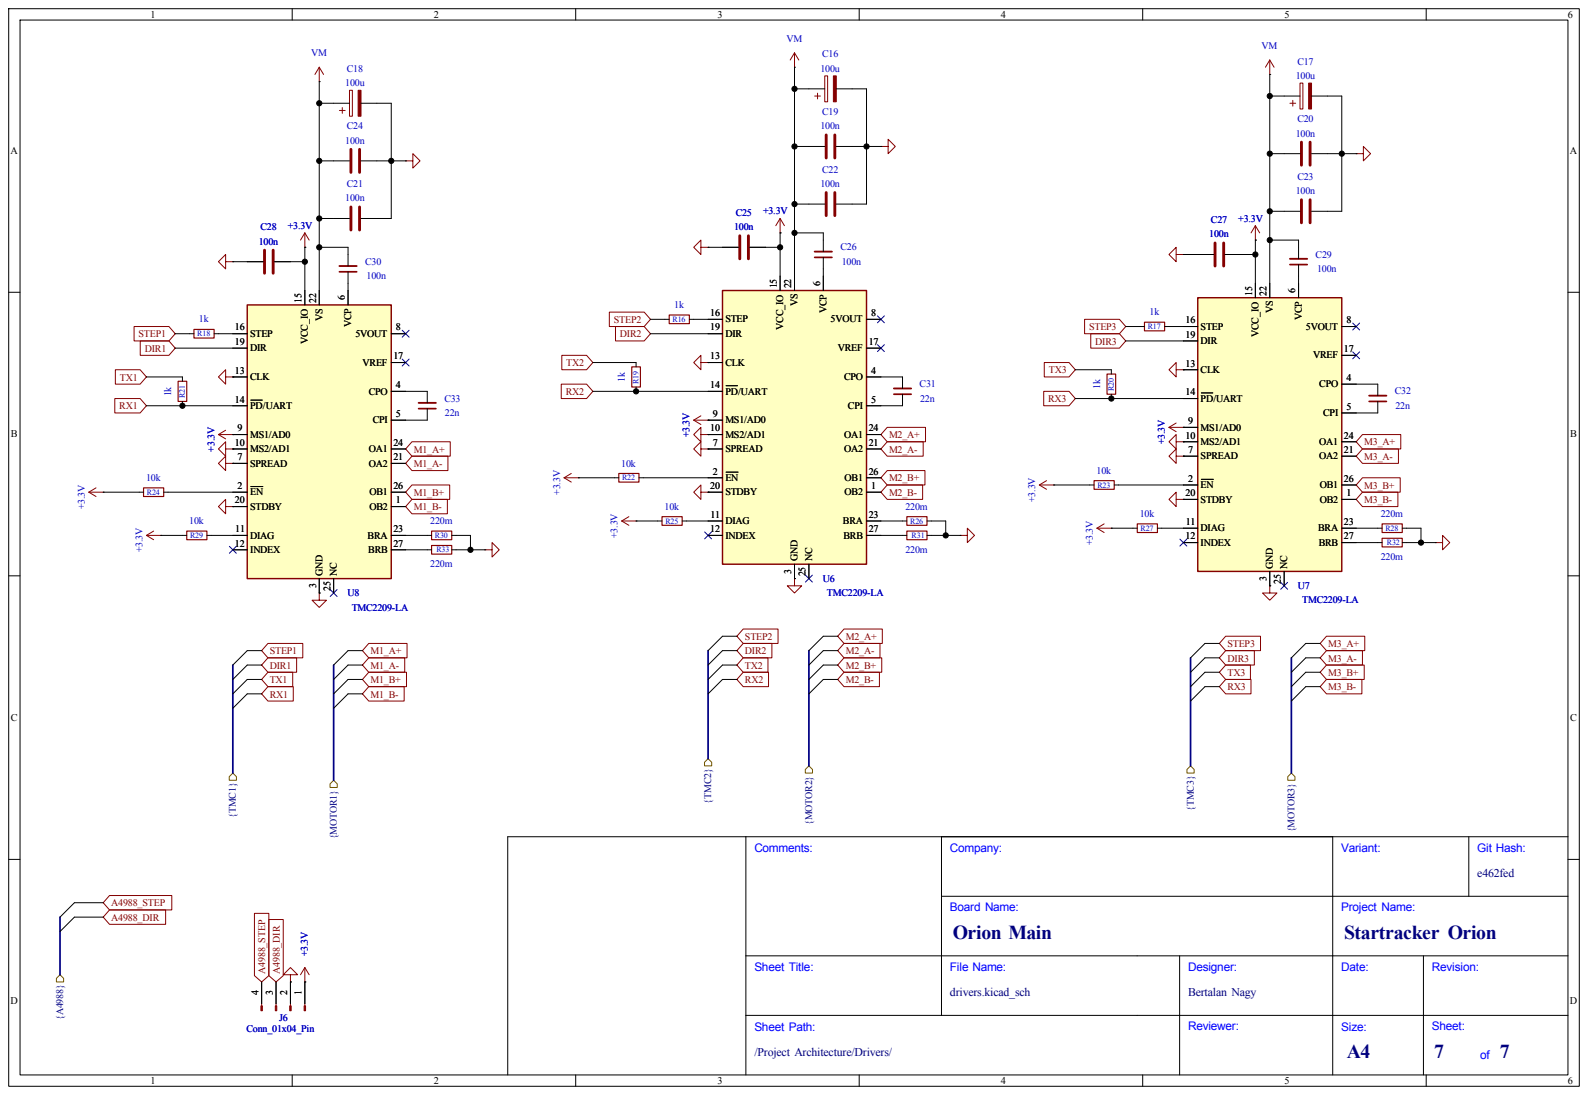
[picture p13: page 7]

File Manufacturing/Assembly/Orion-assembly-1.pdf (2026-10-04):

# Orion Main Assembly Document

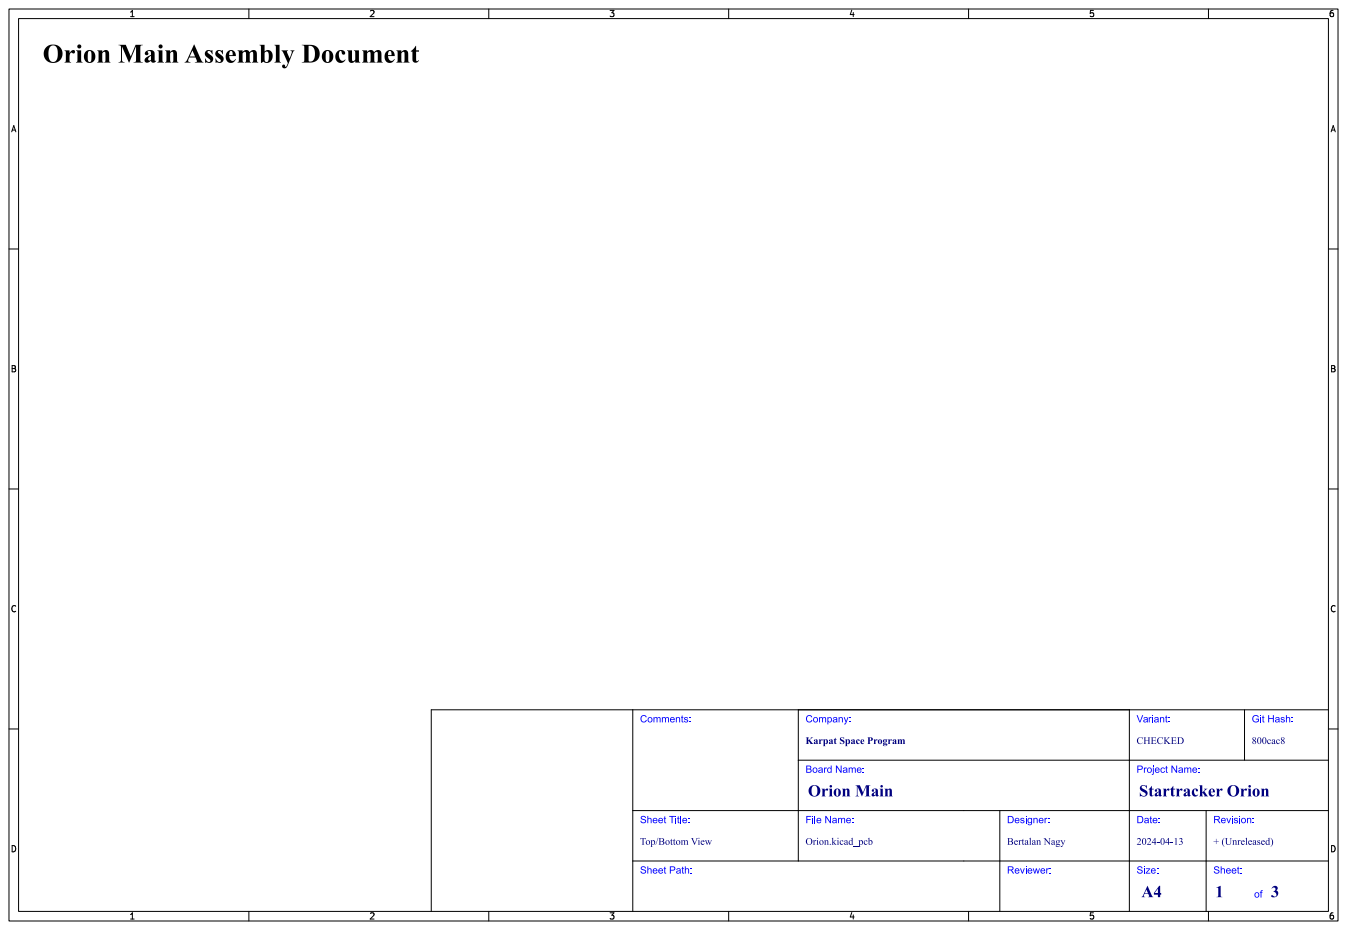
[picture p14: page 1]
Git; Hash:; 800cac8; Comments:; Sheet Path:; Sheet Title:; File Name:; Orion Main; Startracker Orion; Company:; CHECKED; Variant:; Board Name:; Orion.kicad_pcb; Bertalan Nagy; Designer:; Reviewer:; Project Name:; Date:; + (Unreleased); Revision:; Size:; Sheet: 1

Karpat Space Program

Top/Bottom View

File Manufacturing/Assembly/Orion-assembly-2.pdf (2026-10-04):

# Top Assembly (Scale 1:1)

# Orion Main Assembly Document

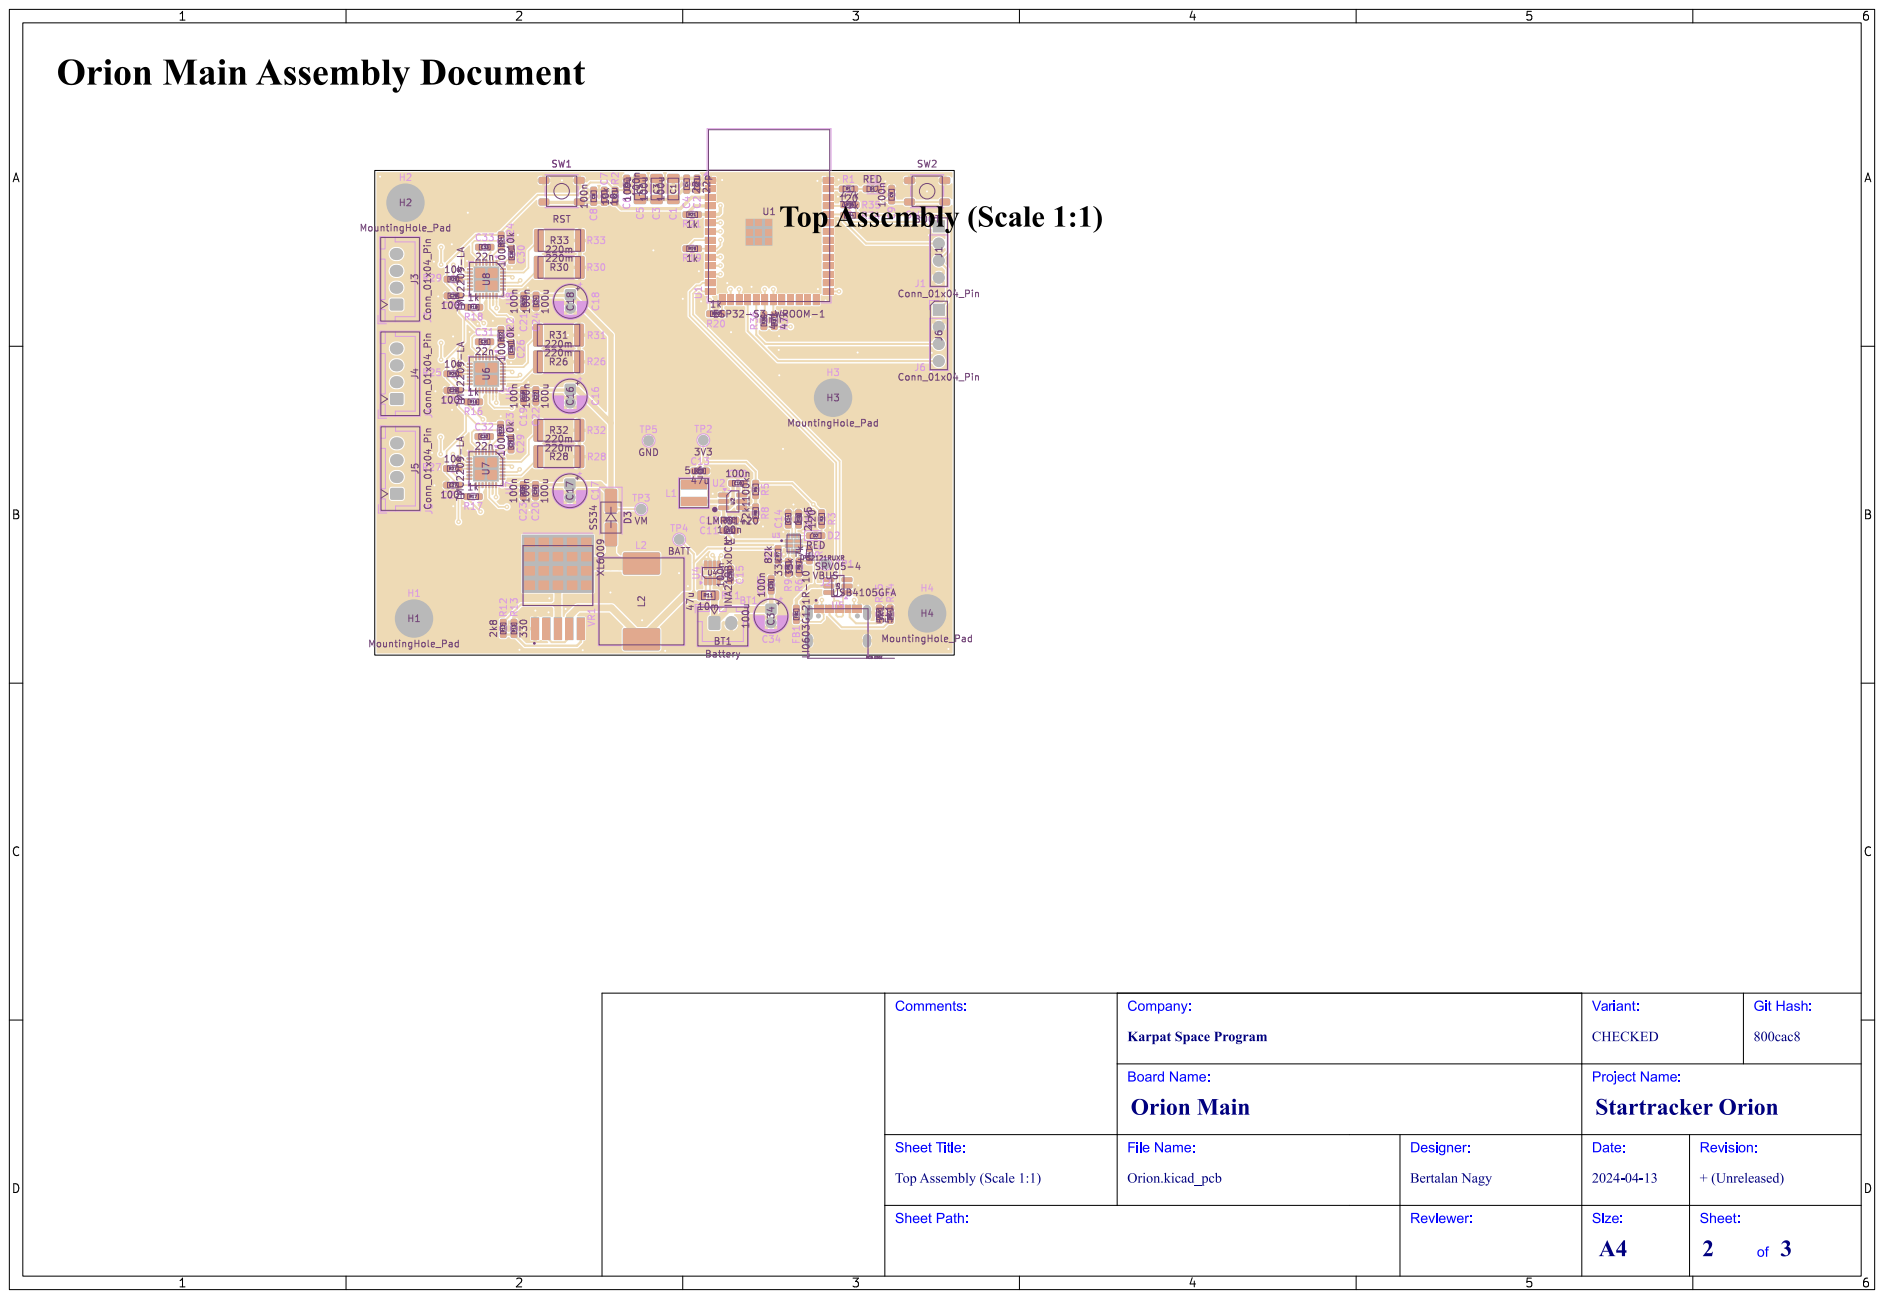
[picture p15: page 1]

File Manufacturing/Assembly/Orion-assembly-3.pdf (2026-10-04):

# Bottom Assembly (Scale 1:1)

# Orion Main Assembly Document

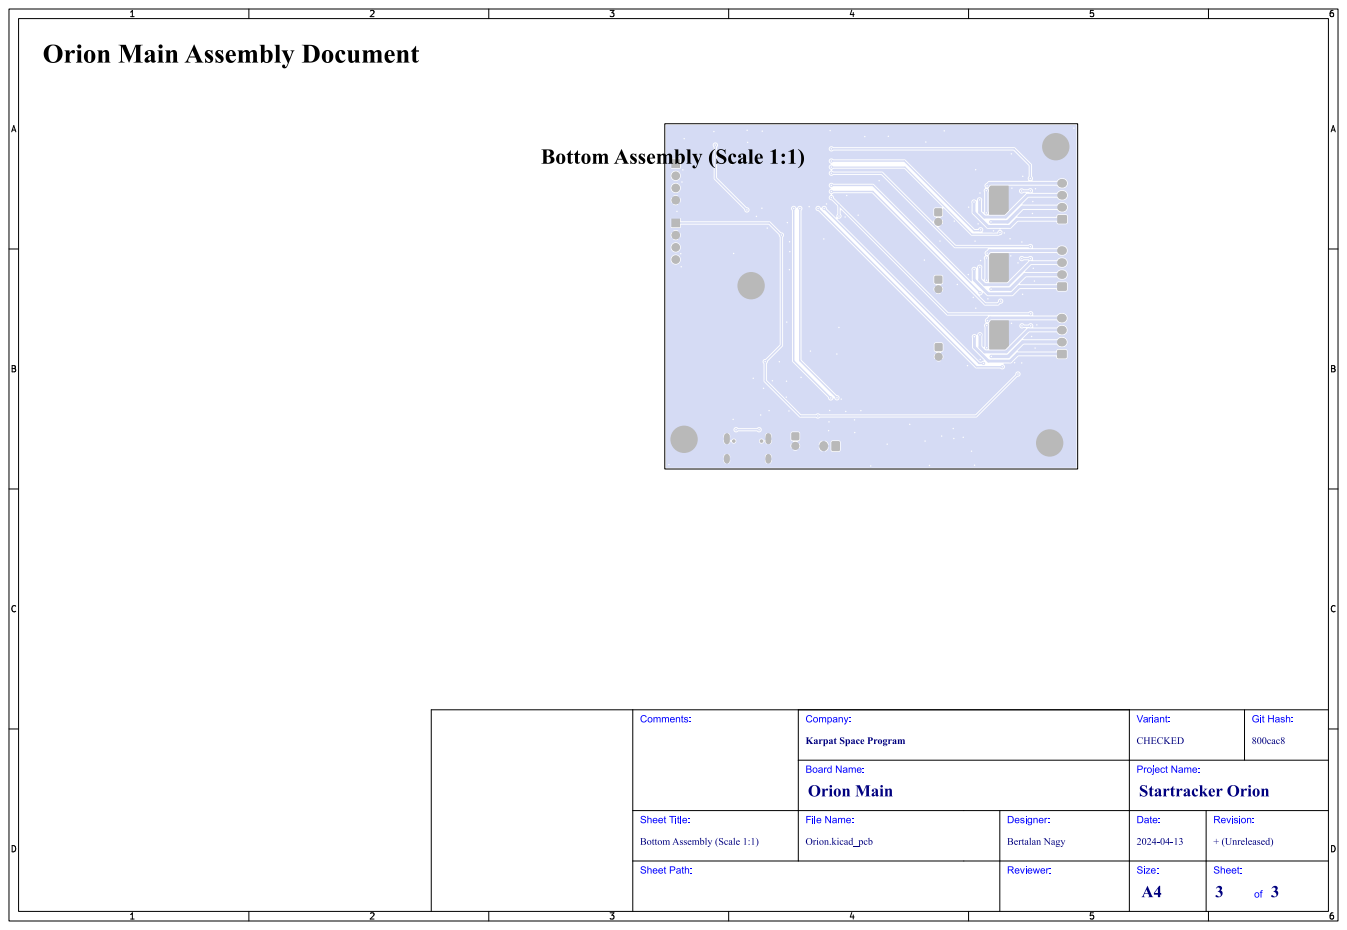
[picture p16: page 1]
Git; Hash:; 800cac8; Comments:; Sheet Path:; Sheet Title:; File Name:; Orion Main; Startracker Orion; Company:; CHECKED; Variant:; Board Name:; Orion.kicad_pcb; Bertalan Nagy; Designer:; Reviewer:; Project Name:; Date:; + (Unreleased); Revision:; Size:; Sheet: 3

Karpat Space Program

Bottom Assembly (Scale 1:1)

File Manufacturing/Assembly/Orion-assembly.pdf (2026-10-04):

# Orion Main Assembly Document

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

Karpat Space Program

Top/Bottom View

# Top Assembly (Scale 1:1)

# Orion Main Assembly Document


# Bottom Assembly (Scale 1:1)

# Orion Main Assembly Document

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

Karpat Space Program

Bottom Assembly (Scale 1:1)

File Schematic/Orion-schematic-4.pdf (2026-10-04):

22p C4

# 10u D1 RED


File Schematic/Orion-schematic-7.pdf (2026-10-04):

# R29 10k C28

100uC29


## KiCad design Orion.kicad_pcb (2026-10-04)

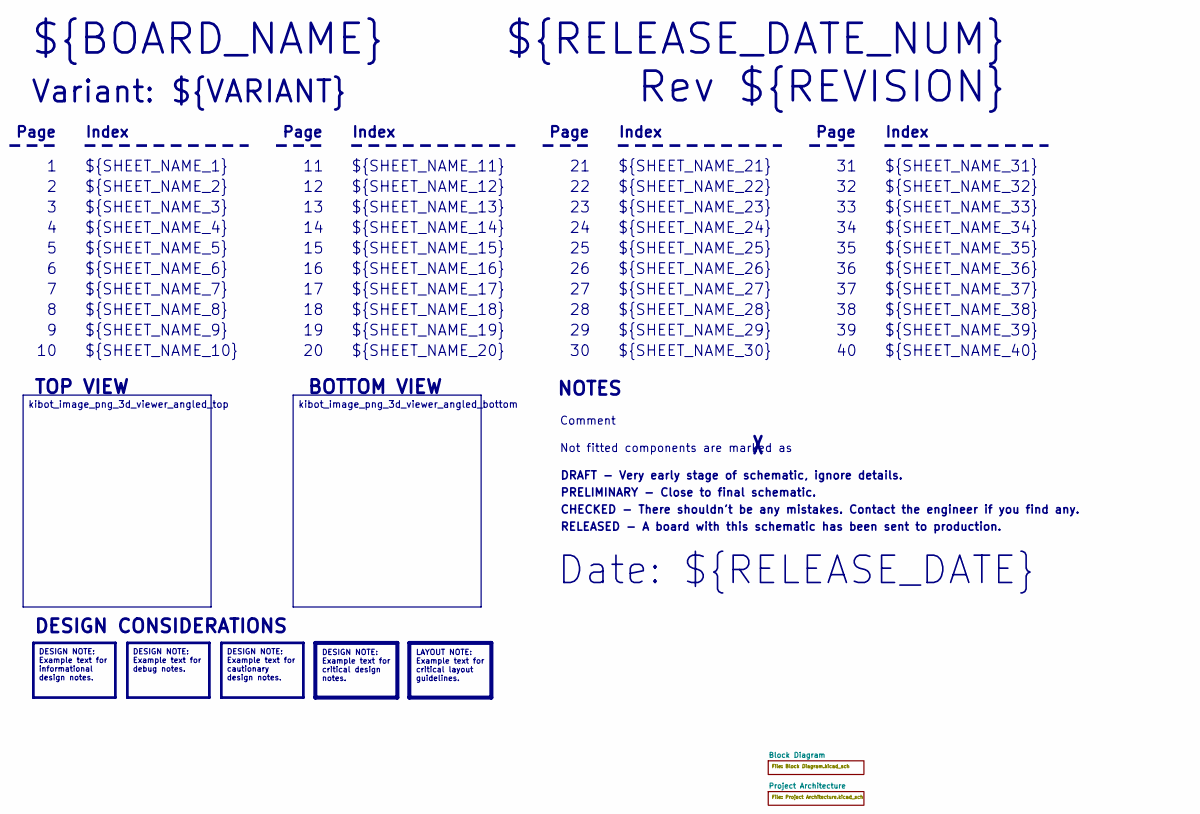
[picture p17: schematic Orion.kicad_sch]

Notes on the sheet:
Variant: ${VARIANT}
RELEASED - A board with this schematic has been sent to production.
${SHEET_NAME_24}
Index
Page
PRELIMINARY - Close to final schematic.
${SHEET_NAME_22}
DRAFT - Very early stage of schematic, ignore details.
${SHEET_NAME_12}
${SHEET_NAME_8}
${SHEET_NAME_2}
${SHEET_NAME_5}
${SHEET_NAME_20}
${SHEET_NAME_23}
${RELEASE_DATE_NUM}
${SHEET_NAME_35}
Not fitted components are marked as
${SHEET_NAME_11}
${SHEET_NAME_6}
${SHEET_NAME_37}
${SHEET_NAME_26}
${SHEET_NAME_36}
Rev ${REVISION}
${SHEET_NAME_15}
CHECKED - There shouldn't be any mistakes. Contact the engineer if you find any.
BOTTOM VIEW
${SHEET_NAME_14}
${SHEET_NAME_21}
${SHEET_NAME_17}
${SHEET_NAME_18}
Date: ${RELEASE_DATE}
${SHEET_NAME_7}
${SHEET_NAME_31}
${BOARD_NAME}
NOTES
${SHEET_NAME_40}
${SHEET_NAME_39}
${SHEET_NAME_32}
${SHEET_NAME_1}
${SHEET_NAME_9}

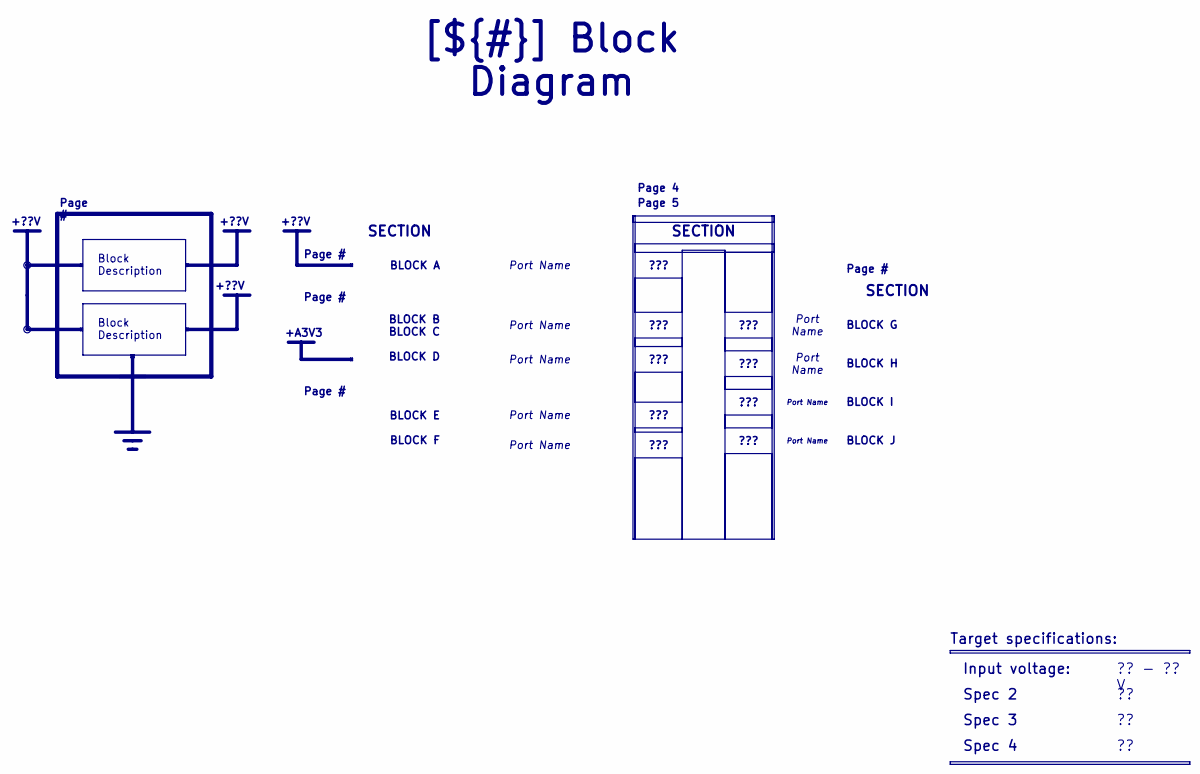
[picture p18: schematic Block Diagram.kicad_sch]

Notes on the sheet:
+??V
+A3V3
SECTION
Spec 4
BLOCK H
BLOCK B BLOCK C BLOCK D
BLOCK I
?? - ?? V
Block Description
???
Port Name
BLOCK G
Page #
Page 4
[${#}] ${TITLE}
Input voltage:
Target specifications:
Spec 3
Spec 2
BLOCK A
BLOCK E BLOCK F
BLOCK J
Page 5

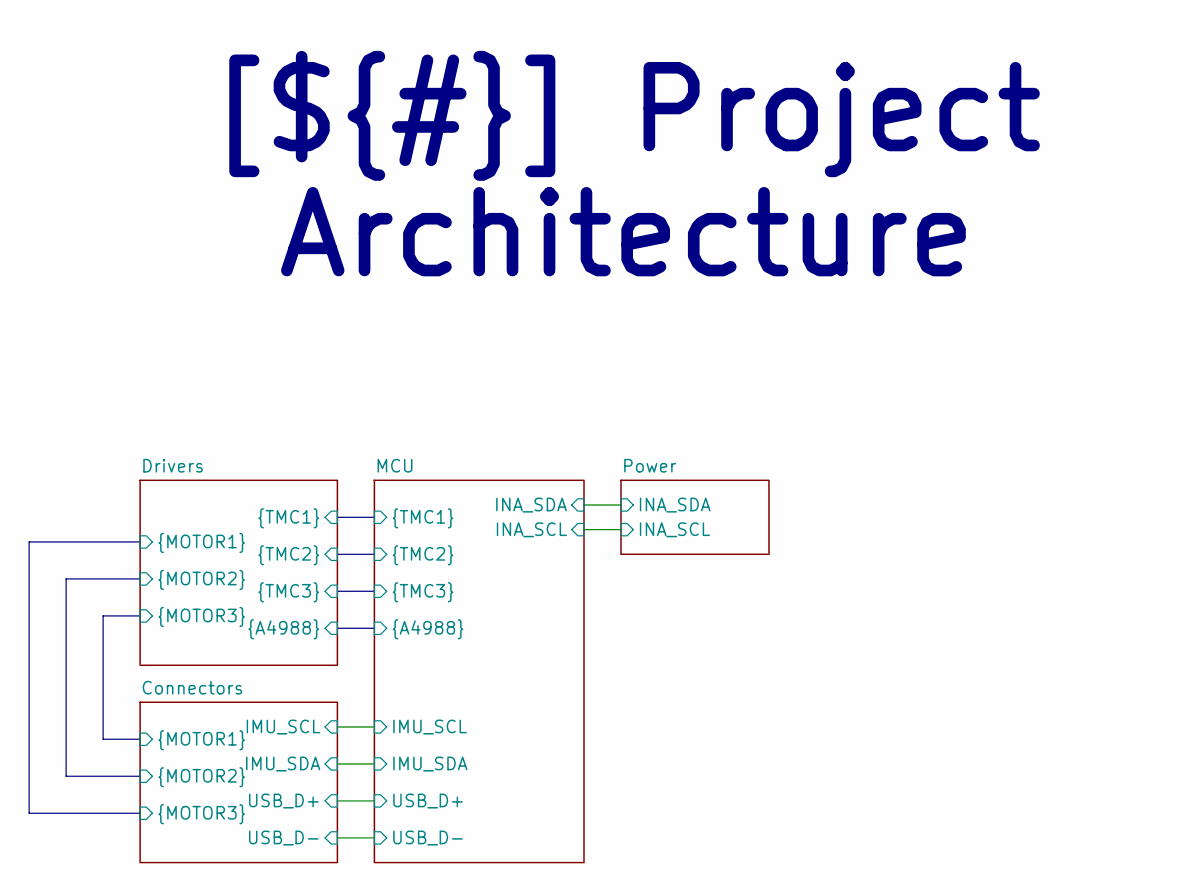
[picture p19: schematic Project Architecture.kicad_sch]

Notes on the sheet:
[${#}] ${TITLE}

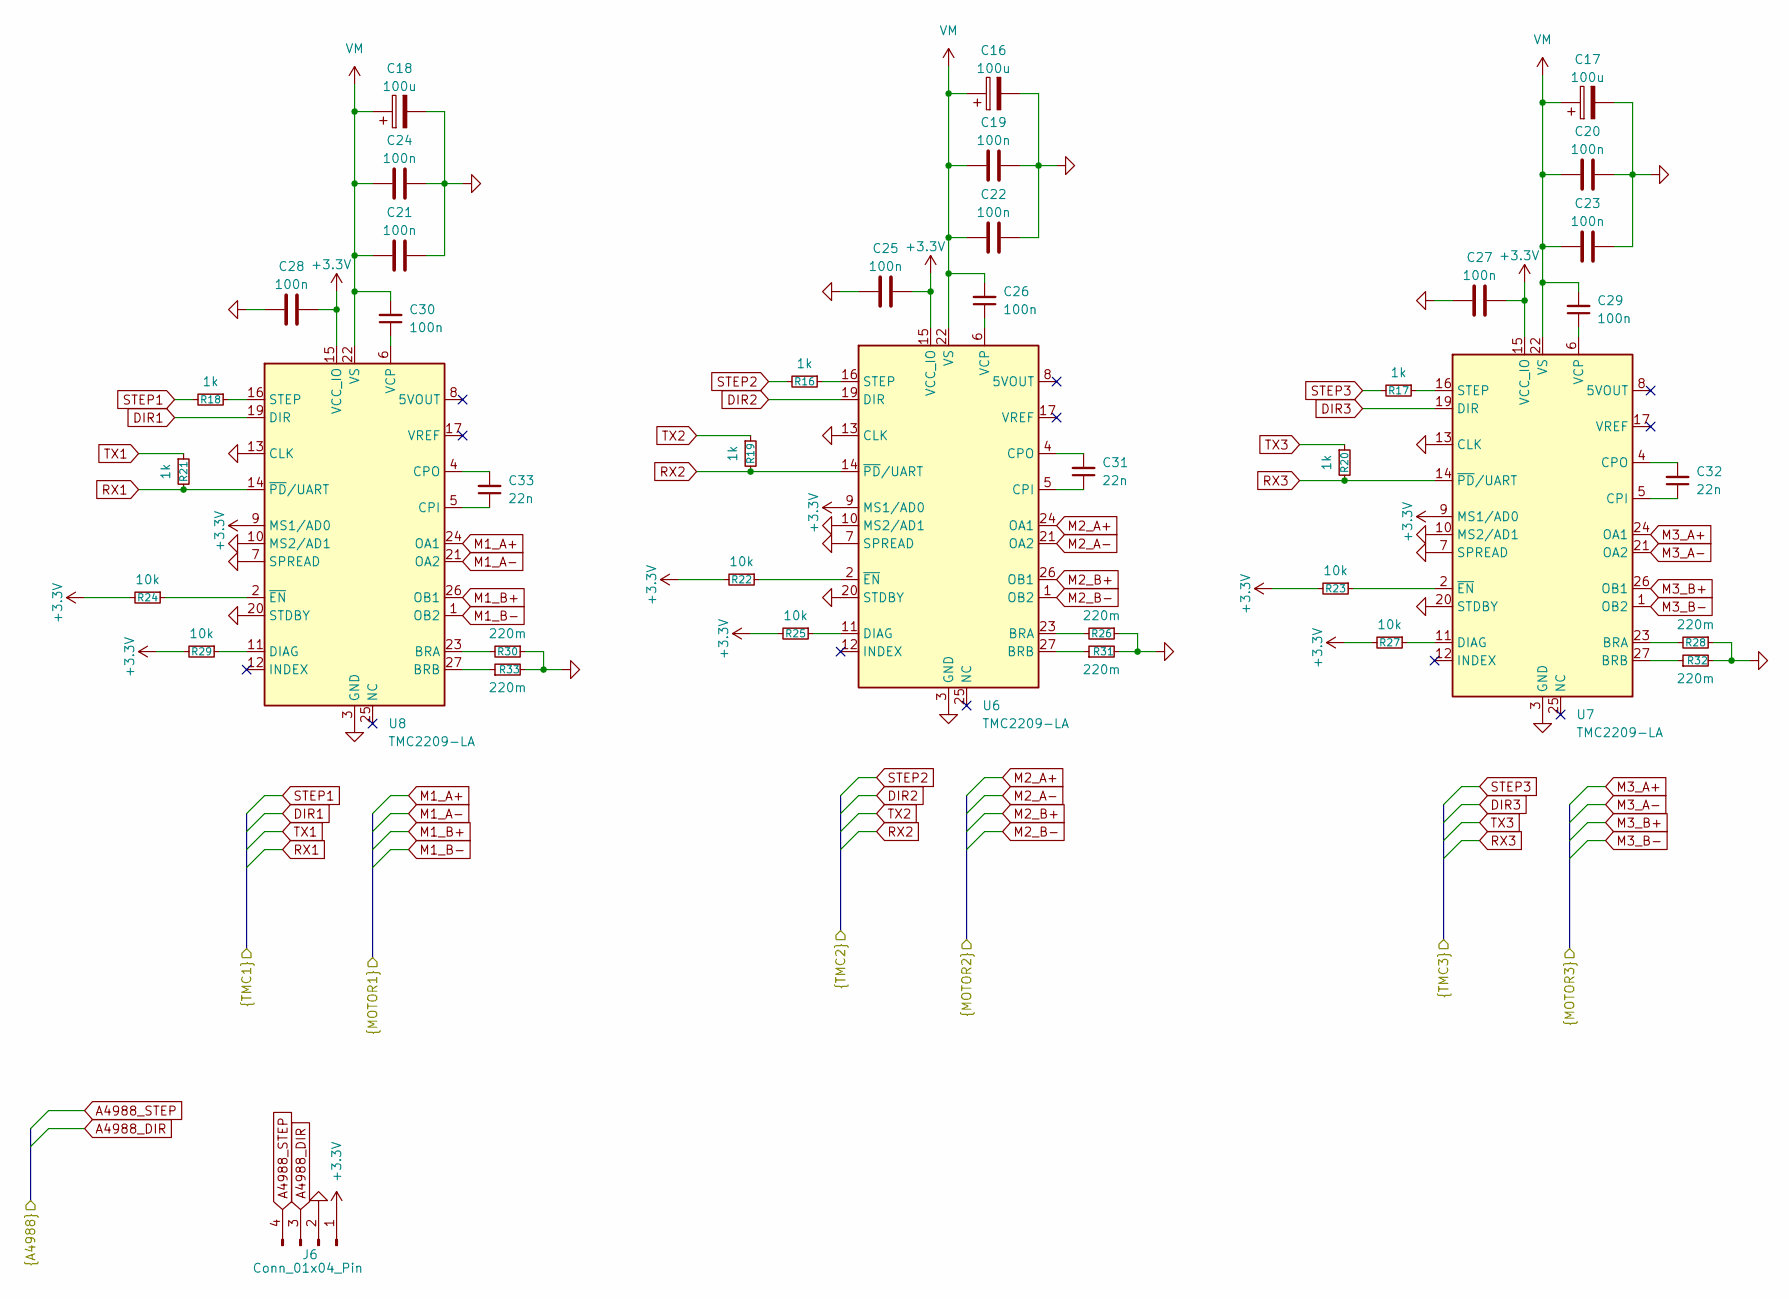
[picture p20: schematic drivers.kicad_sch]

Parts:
C16, C17, C18: 100u; CP_Radial_D5.0mm_P2.00mm
C19, C20, C21, C22, C23, C24, C25, C26, C27, C28, C29, C30: 100n; C_0603_1608Metric_Pad1.08x0.95mm_HandSolder
C31, C32, C33: 22n; C_0603_1608Metric_Pad1.08x0.95mm_HandSolder
J6: Conn_01x04_Pin; PinHeader_1x04_P2.54mm_Vertical
R16, R17, R18, R19, R20, R21: 1k; R_0603_1608Metric_Pad0.98x0.95mm_HandSolder
R22, R23, R24, R25, R27, R29: 10k; R_0603_1608Metric_Pad0.98x0.95mm_HandSolder
R26, R28, R30, R31, R32, R33: 220m; R_2512_6332Metric_Pad1.40x3.35mm_HandSolder
U6, U7, U8: TMC2209-LA; VQFN-28-1EP_5x5mm_P0.5mm_EP3.7x3.7mm

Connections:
+3.3V: C25.2, C27.2, C28.2, J6.1, R22.2, R23.2, R24.2, R25.2, R27.2, R29.2, U6.9 (MS1/AD0), U6.15 (VCC_IO), U7.9 (MS1/AD0), U7.15 (VCC_IO), U8.9 (MS1/AD0), U8.15 (VCC_IO); also elsewhere on the board
A4988_DIR: J6.3; also elsewhere on the board
A4988_STEP: J6.4; also elsewhere on the board
DIR1: U8.19 (DIR); also elsewhere on the board
DIR2: U6.19 (DIR); also elsewhere on the board
DIR3: U7.19 (DIR); also elsewhere on the board
GND: C16.2, C17.2, C18.2, C19.2, C20.2, C21.2, C22.2, C23.2, C24.2, C25.1, C27.1, C28.1, J6.2, R26.1, R28.1, R30.1, R31.2, R32.2, R33.2, U6.3 (GND), U6.7 (SPREAD), U6.10 (MS2/AD1), U6.13 (CLK), U6.18 (GND), U6.20 (STDBY), U6.29 (GND), U7.3 (GND), U7.7 (SPREAD), U7.10 (MS2/AD1), U7.13 (CLK), U7.18 (GND), U7.20 (STDBY), U7.29 (GND), U8.3 (GND), U8.7 (SPREAD), U8.10 (MS2/AD1), U8.13 (CLK), U8.18 (GND), U8.20 (STDBY), U8.29 (GND); also elsewhere on the board
M1_A+: U8.24 (OA1); also elsewhere on the board
M1_A-: U8.21 (OA2); also elsewhere on the board
M1_B+: U8.26 (OB1); also elsewhere on the board
M1_B-: U8.1 (OB2); also elsewhere on the board
M2_A+: U6.24 (OA1); also elsewhere on the board
M2_A-: U6.21 (OA2); also elsewhere on the board
M2_B+: U6.26 (OB1); also elsewhere on the board
M2_B-: U6.1 (OB2); also elsewhere on the board
M3_A+: U7.24 (OA1); also elsewhere on the board
M3_A-: U7.21 (OA2); also elsewhere on the board
M3_B+: U7.26 (OB1); also elsewhere on the board
M3_B-: U7.1 (OB2); also elsewhere on the board
unnamed: R26.2, U6.23 (BRA)
unnamed: R31.1, U6.27 (BRB)
unnamed: C31.1, U6.5 (CPI)
unnamed: C31.2, U6.4 (CPO)
unnamed: R25.1, U6.11 (DIAG)
unnamed: R16.1, U6.16 (STEP)
unnamed: C26.1, U6.6 (VCP)
unnamed: R22.1, U6.2 (~EN)
unnamed: R28.2, U7.23 (BRA)
unnamed: R32.1, U7.27 (BRB)
unnamed: C32.1, U7.5 (CPI)
unnamed: C32.2, U7.4 (CPO)
unnamed: R27.1, U7.11 (DIAG)
unnamed: R17.1, U7.16 (STEP)
unnamed: C29.1, U7.6 (VCP)
unnamed: R23.1, U7.2 (~EN)
unnamed: R30.2, U8.23 (BRA)
unnamed: R33.1, U8.27 (BRB)
unnamed: C33.1, U8.5 (CPI)
unnamed: C33.2, U8.4 (CPO)
unnamed: R29.1, U8.11 (DIAG)
unnamed: R18.1, U8.16 (STEP)
unnamed: C30.1, U8.6 (VCP)
unnamed: R24.1, U8.2 (~EN)
RX1: R21.2, U8.14 (~PD/UART); also elsewhere on the board
RX2: R19.2, U6.14 (~PD/UART); also elsewhere on the board
RX3: R20.2, U7.14 (~PD/UART); also elsewhere on the board
STEP1: R18.2; also elsewhere on the board
STEP2: R16.2; also elsewhere on the board
STEP3: R17.2; also elsewhere on the board
TX1: R21.1; also elsewhere on the board
TX2: R19.1; also elsewhere on the board
TX3: R20.1; also elsewhere on the board
VM: C16.1, C17.1, C18.1, C19.1, C20.1, C21.1, C22.1, C23.1, C24.1, C26.2, C29.2, C30.2, U6.22 (VS), U6.28 (VS), U7.22 (VS), U7.28 (VS), U8.22 (VS), U8.28 (VS); also elsewhere on the board

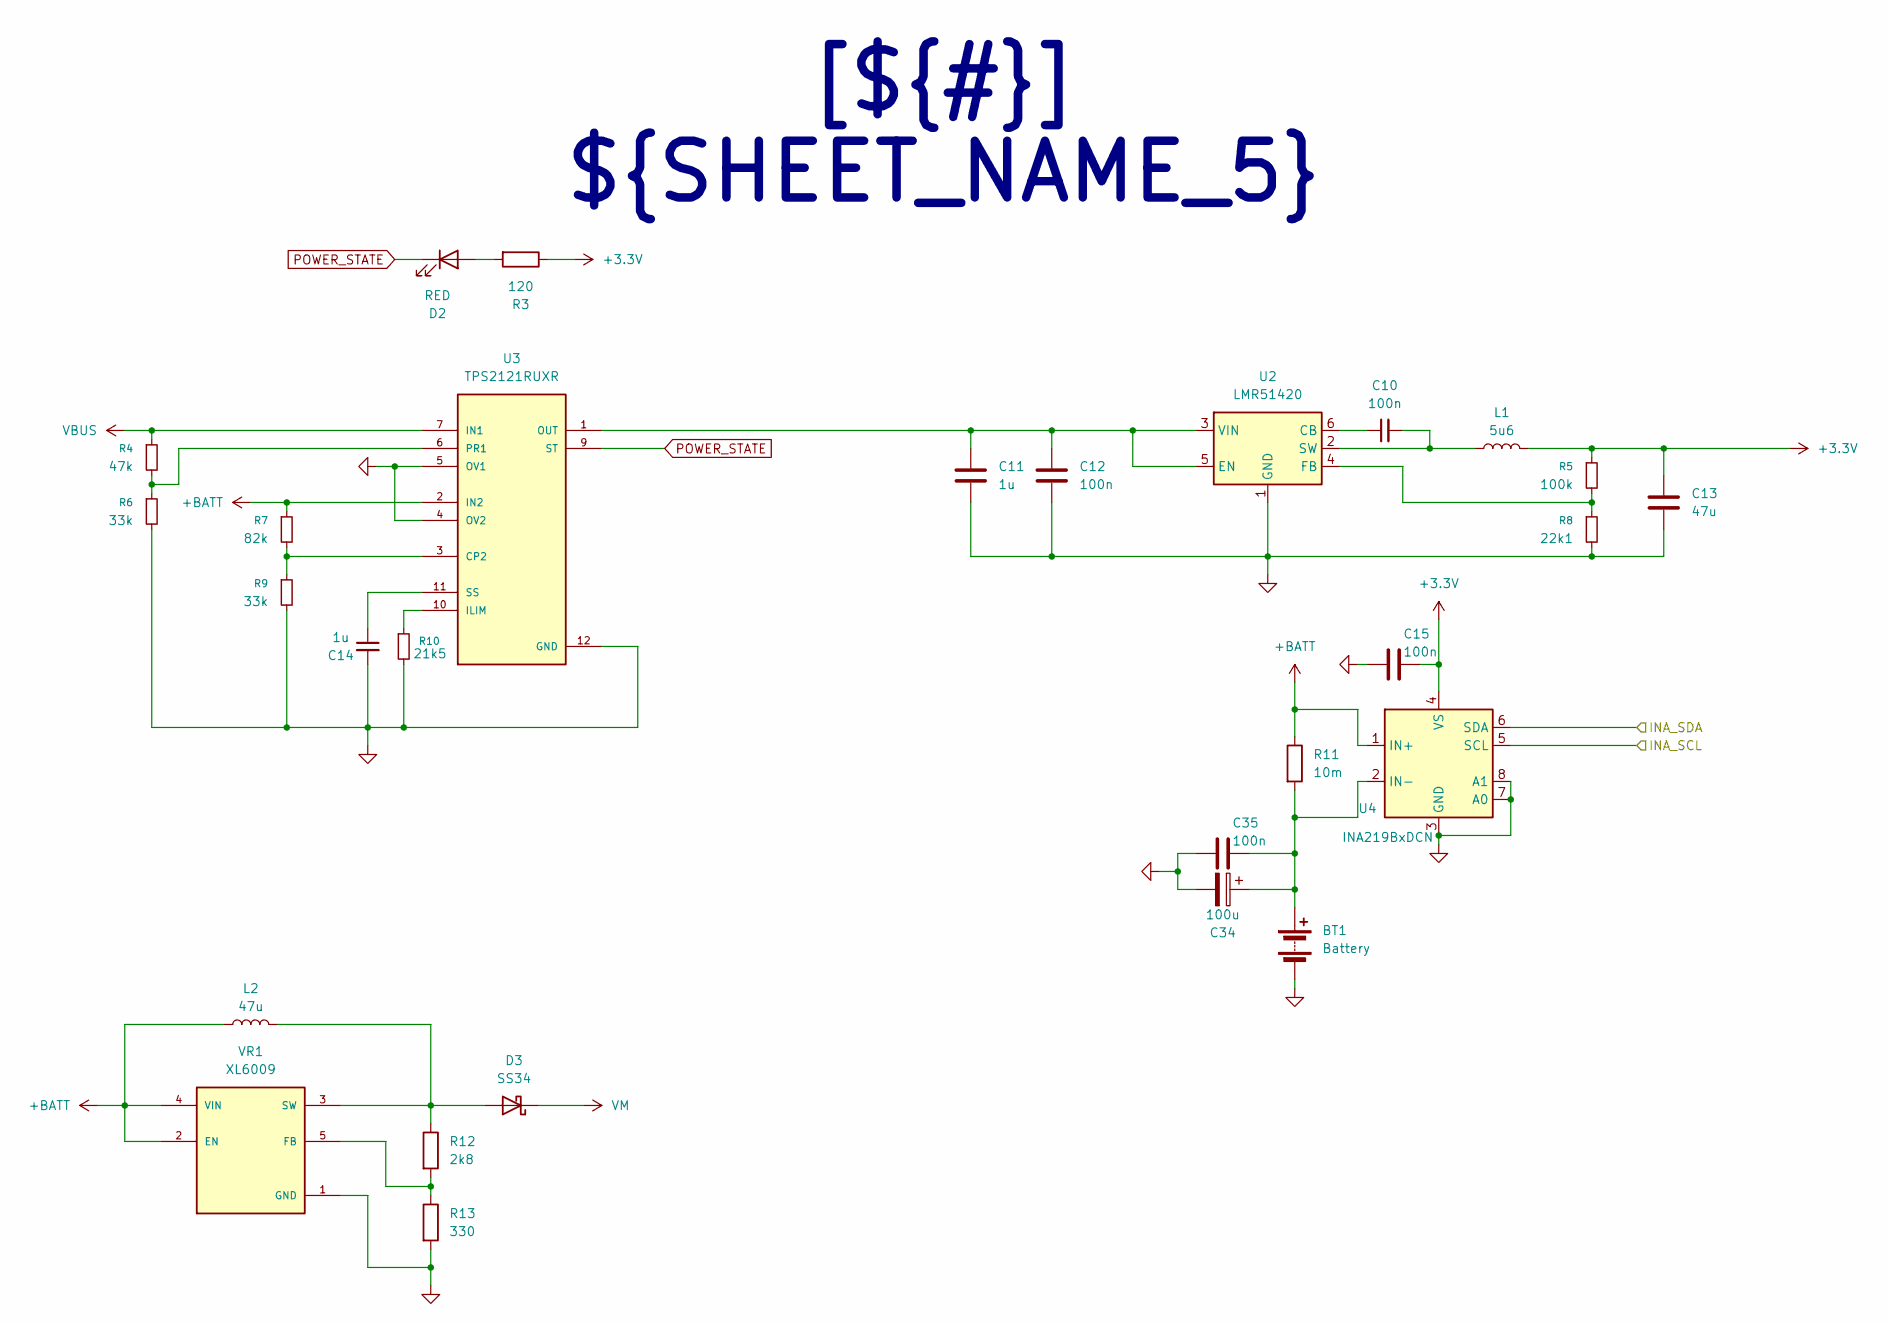
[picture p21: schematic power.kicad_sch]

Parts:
BT1: Battery; JST_XH_B2B-XH-A_1x02_P2.50mm_Vertical
C10, C12, C15, C35: 100n; C_0603_1608Metric_Pad1.08x0.95mm_HandSolder
C11, C14: 1u; C_0603_1608Metric_Pad1.08x0.95mm_HandSolder
C13: 47u; C_0603_1608Metric_Pad1.08x0.95mm_HandSolder
C34: 100u; CP_Radial_D5.0mm_P2.00mm
D2: RED; LED_0603_1608Metric_Pad1.05x0.95mm_HandSolder
D3: SS34; D_SMA_Handsoldering
L1: 5u6; WE-XHMI_4040
L2: 47u; L_Changjiang_FXL1365
R3: 120; R_0603_1608Metric_Pad0.98x0.95mm_HandSolder
R4: 47k; R_0603_1608Metric_Pad0.98x0.95mm_HandSolder
R5: 100k; R_0603_1608Metric_Pad0.98x0.95mm_HandSolder
R6, R9: 33k; R_0603_1608Metric_Pad0.98x0.95mm_HandSolder
R7: 82k; R_0603_1608Metric_Pad0.98x0.95mm_HandSolder
R8: 22k1; R_0603_1608Metric_Pad0.98x0.95mm_HandSolder
R10: 21k5; R_0603_1608Metric_Pad0.98x0.95mm_HandSolder
R11: 10m; R_0805_2012Metric_Pad1.20x1.40mm_HandSolder
R12: 2k8; R_0603_1608Metric_Pad0.98x0.95mm_HandSolder
R13: 330; R_0603_1608Metric_Pad0.98x0.95mm_HandSolder
U2: LMR51420; SOT-23-6_Handsoldering
U3: TPS2121RUXR; IC_TPS2121RUXR
U4: INA219BxDCN; SOT-23-8
VR1: XL6009; DPAK170P1435X465-6N; PARTREV 1.1

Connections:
+3.3V: C13.1, C15.2, L1.2, R3.1, R5.1, U4.4 (VS); also elsewhere on the board
+BATT: L2.1, R7.1, R11.1, U3.2 (IN2), U3.2_1 (IN2), U4.1 (IN+), VR1.2 (EN), VR1.4 (VIN); also elsewhere on the board
/Project Architecture/MCU/INA_SCL: U4.5 (SCL); also elsewhere on the board
/Project Architecture/MCU/INA_SDA: U4.6 (SDA); also elsewhere on the board
GND: BT1.2 (-), C11.2, C12.2, C13.2, C14.2, C15.1, C34.2, C35.1, R6.2, R8.2, R9.2, R10.2, R13.2, U2.1 (GND), U3.4 (OV2), U3.5 (OV1), U3.12 (GND), U4.3 (GND), U4.7 (A0), U4.8 (A1), VR1.1 (GND); also elsewhere on the board
unnamed: BT1.1 (+), C34.1, C35.2, R11.2, U4.2 (IN-)
unnamed: D2.2 (A), R3.2
unnamed: D3.2 (A), L2.2, R12.1, VR1.3 (SW), VR1.6 (SW)
unnamed: C10.1, U2.6 (CB)
unnamed: C11.1, C12.1, U2.3 (VIN), U2.5 (EN), U3.1 (OUT), U3.1_1 (OUT), U3.8 (OUT), U3.8_1 (OUT)
unnamed: R5.2, R8.1, U2.4 (FB)
unnamed: C10.2, L1.1, U2.2 (SW)
unnamed: R7.2, R9.1, U3.3 (CP2)
unnamed: R10.1, U3.10 (ILIM)
unnamed: R4.2, R6.1, U3.6 (PR1)
unnamed: C14.1, U3.11 (SS)
unnamed: R12.2, R13.1, VR1.5 (FB)
POWER_STATE: D2.1 (K), U3.9 (ST)
VBUS: R4.1, U3.7 (IN1), U3.7_1 (IN1); also elsewhere on the board
VM: D3.1 (K); also elsewhere on the board

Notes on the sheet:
[${#}] ${SHEET_NAME_5}

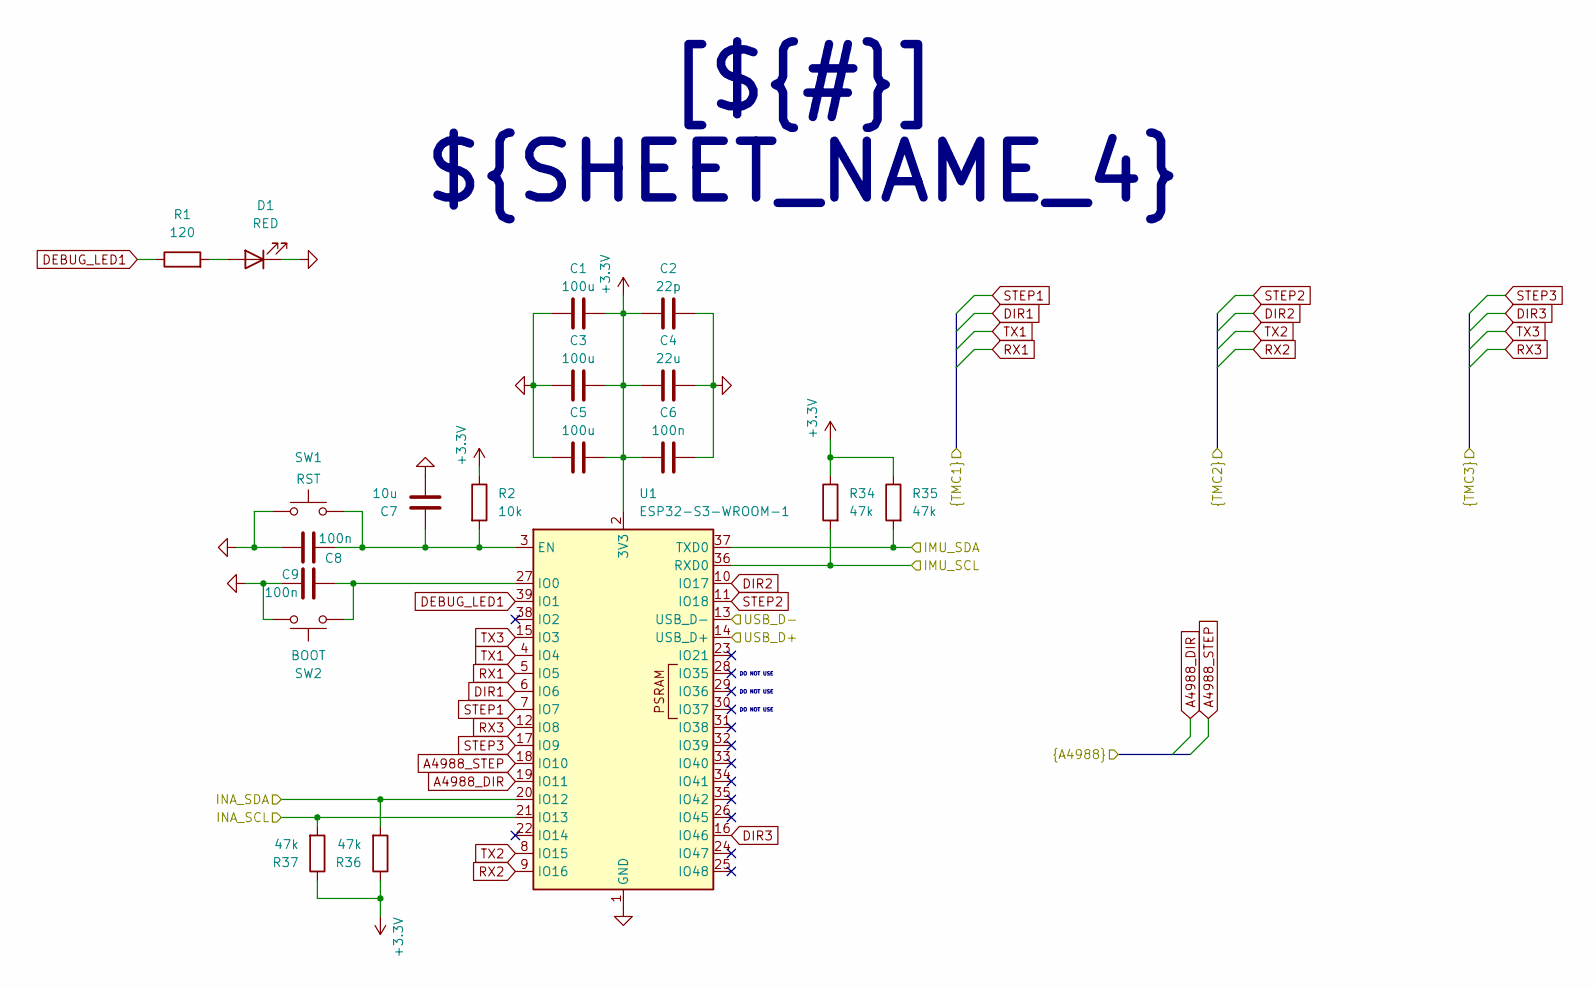
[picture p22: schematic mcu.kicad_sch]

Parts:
C1, C3, C5: 100u; C_1206_3216Metric_Pad1.33x1.80mm_HandSolder
C2: 22p; C_0603_1608Metric_Pad1.08x0.95mm_HandSolder
C4: 22u; C_0603_1608Metric_Pad1.08x0.95mm_HandSolder
C6, C8, C9: 100n; C_0603_1608Metric_Pad1.08x0.95mm_HandSolder
C7: 10u; C_0603_1608Metric_Pad1.08x0.95mm_HandSolder
D1: RED; LED_0603_1608Metric_Pad1.05x0.95mm_HandSolder
R1: 120; R_0603_1608Metric_Pad0.98x0.95mm_HandSolder
R2: 10k; R_0603_1608Metric_Pad0.98x0.95mm_HandSolder
R34, R35, R36, R37: 47k; R_0603_1608Metric_Pad0.98x0.95mm_HandSolder
SW1: RST; SW_SPST_PTS647_Sx38
SW2: BOOT; SW_SPST_PTS647_Sx38
U1: ESP32-S3-WROOM-1; ESP32-S3-WROOM-1_novias

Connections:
+3.3V: C1.2, C2.1, C3.2, C4.1, C5.2, C6.1, R2.1, R34.1, R35.1, R36.1, R37.1, U1.2 (3V3); also elsewhere on the board
/Project Architecture/Connectors/IMU_SCL: R34.2, U1.36 (RXD0); also elsewhere on the board
/Project Architecture/Connectors/IMU_SDA: R35.2, U1.37 (TXD0); also elsewhere on the board
/Project Architecture/Connectors/USB_D+: U1.14 (USB_D+); also elsewhere on the board
/Project Architecture/Connectors/USB_D-: U1.13 (USB_D-); also elsewhere on the board
/Project Architecture/MCU/INA_SCL: R37.2, U1.21 (IO13); also elsewhere on the board
/Project Architecture/MCU/INA_SDA: R36.2, U1.20 (IO12); also elsewhere on the board
A4988_DIR: U1.19 (IO11); also elsewhere on the board
A4988_STEP: U1.18 (IO10); also elsewhere on the board
DEBUG_LED1: R1.1, U1.39 (IO1)
DIR1: U1.6 (IO6); also elsewhere on the board
DIR2: U1.10 (IO17); also elsewhere on the board
DIR3: U1.16 (IO46); also elsewhere on the board
GND: C1.1, C2.2, C3.1, C4.2, C5.1, C6.2, C7.2, C8.1, C9.1, D1.1 (K), SW1.1, SW2.1, U1.1 (GND), U1.40 (GND), U1.41 (GND); also elsewhere on the board
unnamed: D1.2 (A), R1.2
unnamed: C7.1, C8.2, R2.2, SW1.2, U1.3 (EN)
unnamed: C9.2, SW2.2, U1.27 (IO0)
RX1: U1.5 (IO5); also elsewhere on the board
RX2: U1.9 (IO16); also elsewhere on the board
RX3: U1.12 (IO8); also elsewhere on the board
STEP1: U1.7 (IO7); also elsewhere on the board
STEP2: U1.11 (IO18); also elsewhere on the board
STEP3: U1.17 (IO9); also elsewhere on the board
TX1: U1.4 (IO4); also elsewhere on the board
TX2: U1.8 (IO15); also elsewhere on the board
TX3: U1.15 (IO3); also elsewhere on the board

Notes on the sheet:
DO NOT USE
[${#}] ${SHEET_NAME_4}

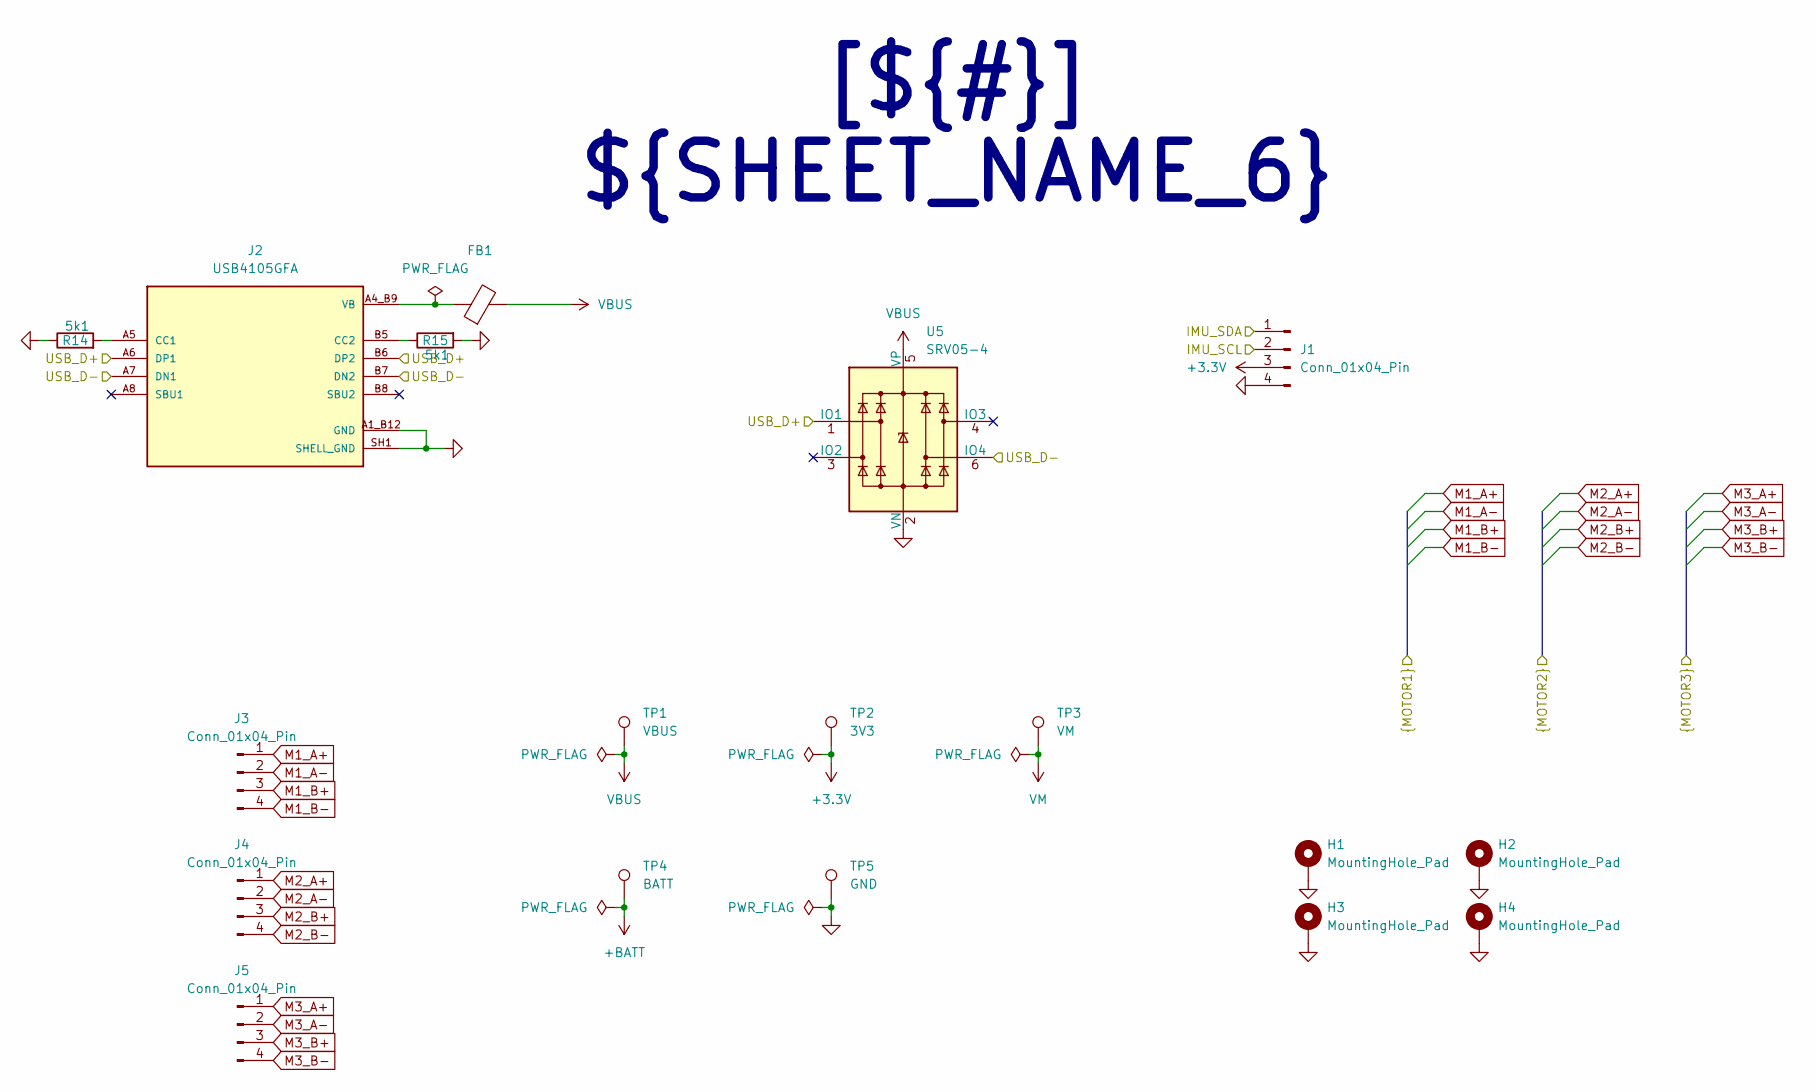
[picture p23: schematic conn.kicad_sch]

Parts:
FB1: LI0603G121R-10; L_0603_1608Metric_Pad1.05x0.95mm_HandSolder
H1, H2, H3, H4: MountingHole_Pad; MountingHole_3.2mm_M3_DIN965_Pad
J1: Conn_01x04_Pin; PinHeader_1x04_P2.54mm_Vertical
J2: USB4105GFA; GCT_USB4105GFA; PARTREV B3
J3, J4, J5: Conn_01x04_Pin; JST_XH_B4B-XH-A_1x04_P2.50mm_Vertical
R14, R15: 5k1; R_0603_1608Metric_Pad0.98x0.95mm_HandSolder
TP1: VBUS; TestPoint_Pad_D1.5mm
TP2: 3V3; TestPoint_Pad_D1.5mm
TP3: VM; TestPoint_Pad_D1.5mm
TP4: BATT; TestPoint_Pad_D1.5mm
TP5: GND; TestPoint_Pad_D1.5mm
U5: SRV05-4; SOT-23-6_Handsoldering

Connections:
+3.3V: J1.3, TP2.1 (1_1); also elsewhere on the board
+BATT: TP4.1 (1_1); also elsewhere on the board
/Project Architecture/Connectors/IMU_SCL: J1.2; also elsewhere on the board
/Project Architecture/Connectors/IMU_SDA: J1.1; also elsewhere on the board
/Project Architecture/Connectors/USB_D+: J2.A6 (DP1), J2.B6 (DP2), U5.1 (IO1); also elsewhere on the board
/Project Architecture/Connectors/USB_D-: J2.A7 (DN1), J2.B7 (DN2), U5.6 (IO4); also elsewhere on the board
GND: H1.1 (1_1), H2.1 (1_1), H3.1 (1_1), H4.1 (1_1), J1.4, J2.A1_B12 (GND), J2.B1_A12 (GND), J2.SH1 (SHELL_GND), J2.SH2 (SHELL_GND), J2.SH3 (SHELL_GND), J2.SH4 (SHELL_GND), R14.1, R15.2, TP5.1 (1_1), U5.2 (VN); also elsewhere on the board
M1_A+: J3.1; also elsewhere on the board
M1_A-: J3.2; also elsewhere on the board
M1_B+: J3.3; also elsewhere on the board
M1_B-: J3.4; also elsewhere on the board
M2_A+: J4.1; also elsewhere on the board
M2_A-: J4.2; also elsewhere on the board
M2_B+: J4.3; also elsewhere on the board
M2_B-: J4.4; also elsewhere on the board
M3_A+: J5.1; also elsewhere on the board
M3_A-: J5.2; also elsewhere on the board
M3_B+: J5.3; also elsewhere on the board
M3_B-: J5.4; also elsewhere on the board
unnamed: J2.A5 (CC1), R14.2
unnamed: J2.B5 (CC2), R15.1
VB: FB1.1, J2.A4_B9 (VB), J2.B4_A9 (VB)
VBUS: FB1.2, TP1.1 (1_1), U5.5 (VP); also elsewhere on the board
VM: TP3.1 (1_1); also elsewhere on the board

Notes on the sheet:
[${#}] ${SHEET_NAME_6}

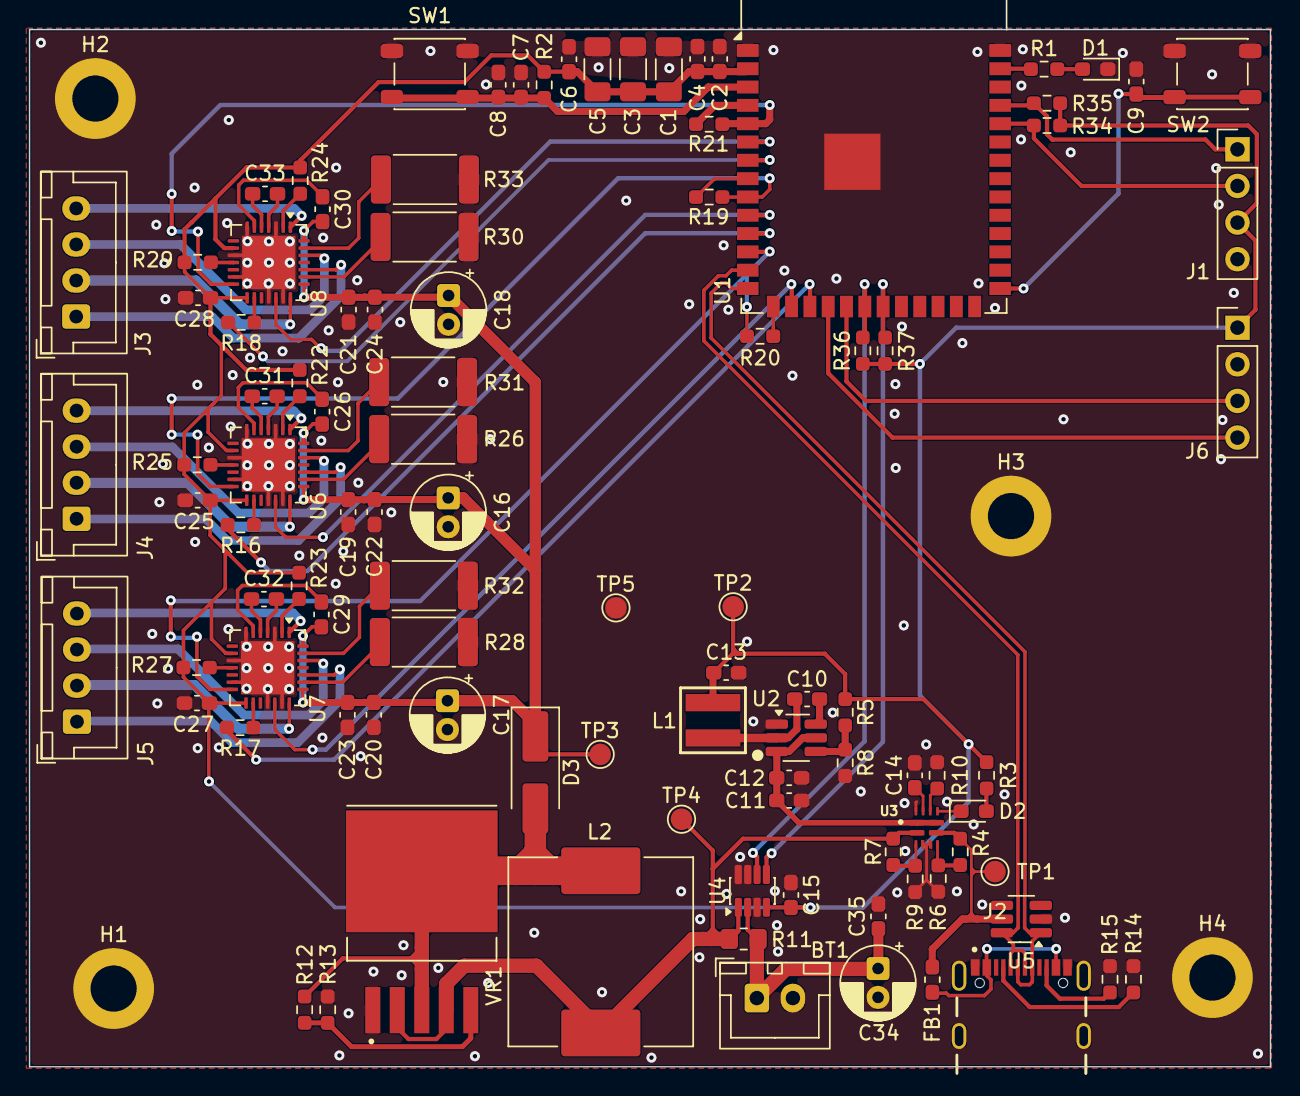
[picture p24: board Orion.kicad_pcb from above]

Board: 2 copper layers, 86.1 x 71.9 mm, 105 parts (0 on the bottom side), 81 nets.

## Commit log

2026-08-14 PCB work
    [Block Diagram.kicad_sch, Orion.kicad_sch, Project Architecture.kicad_sch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]
2026-08-20 PCB schematic design
    [Project Architecture.kicad_sch, conn.kicad_sch, drivers.kicad_sch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]
2026-08-24 Connected hierarchical boards
    [Project Architecture.kicad_sch, conn.kicad_sch, mcu.kicad_sch]
2026-09-10 Finished design
    [Orion.kicad_pcb, conn.kicad_sch, drivers.kicad_sch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]
2026-09-10 Update Outputs
    [Orion-(L1-L4)_NPTH_drill_table.csv, Orion-(L1-L4)_drill_table.csv, Orion-bom.csv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]
2026-09-19 Final tweaks
    [Orion-B_Mask.gbr, Orion-B_Paste.gbr, Orion-B_Silkscreen.gbr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]
2026-09-20 Fab file organizing
    [Orion-B_Mask.gbr, Orion-B_Paste.gbr, Orion-B_Silkscreen.gbr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]
2026-09-21 Minor tweaks
    [conn.kicad_sch, power.kicad_sch]
2026-09-28 Started troublefixing
    [conn.kicad_sch, drivers.kicad_sch, mcu.kicad_sch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]
2026-09-29 Corrected wrong footprints
    [drivers.kicad_sch, power.kicad_sch]
2026-09-29 Started rerouting changes
    [Orion.kicad_pcb, conn.kicad_sch, drivers.kicad_sch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]
2026-10-04 Completed changes
    [Orion.kicad_pcb]
2026-10-04 Finalized design
    [Orion.kicad_pcb]
